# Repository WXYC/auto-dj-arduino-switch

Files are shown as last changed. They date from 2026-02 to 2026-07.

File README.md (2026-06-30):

# Auto DJ Arduino Switch

An Arduino Giga R1 WiFi sketch that **reports** the mixing board's AUX relay state and a manual toggle button to the [auto-dj-orchestrator](https://github.com/WXYC/auto-dj-orchestrator) over a WebSocket management channel (HTTP fallback over WiFi). The orchestrator owns all activation logic — it subscribes to AzuraCast and writes the flowsheet (to Backend-Service, which mirrors to tubafrenzy). This board is a "dumb" reporter: it reports inputs and drives a status LED.

> **Note:** Earlier firmware wrote tracks to tubafrenzy directly. That responsibility now lives in the orchestrator; the Arduino no longer polls AzuraCast or writes flowsheets. See [docs/networking-spec.md](docs/networking-spec.md).

## Why?

When auto DJ is playing and no DJ is logged into the flowsheet, those tracks are not recorded in WXYC's playback history. The orchestrator fills that gap; this device tells it when the auto DJ is on the air (relay) and lets an operator toggle it manually (button).

## Architecture

```mermaid
flowchart LR
    MB["Mixing Board<br>AUX Relay<br>(dry contact)"] -->|D2 pin| ARD["Arduino Giga R1 WiFi<br>Reports relay + button"]
    BTN["Toggle button"] -->|D5 pin| ARD
    ARD <-->|"WS mgmt channel<br>(HTTP fallback)"| ORCH["auto-dj-orchestrator"]
    ORCH <-->|Now Playing| AZ["AzuraCast<br>remote.wxyc.org"]
    ORCH -->|join / entry / end| BS["Backend-Service<br>(mirrors to tubafrenzy)"]
```

### Planned Architecture

A management server will sit between AzuraCast and the Arduino, subscribing to AzuraCast's Centrifugo real-time feed and relaying Now Playing updates over a single WebSocket that also carries management commands and heartbeat telemetry. An Ethernet shield provides the stable persistent connection required for WebSocket; WiFi remains as a fallback with direct AzuraCast polling.

```mermaid
flowchart LR
    MB["Mixing Board<br>AUX Relay"] -->|D2| ARD
    BTN["Toggle button"] -->|D5| ARD
    ARD["Arduino Giga R1 WiFi<br>(+ Ethernet Shield, Phase 2)"]
    ARD <-->|"WS mgmt channel<br>(heartbeat, button_toggle,<br>ack, commands)<br>HTTP fallback over WiFi"| ORCH["auto-dj-orchestrator"]
    ORCH <-->|now-playing| AZ["AzuraCast"]
    ORCH -->|flowsheet writes| BS["Backend-Service<br>(mirrors to tubafrenzy)"]
```

See [docs/networking-spec.md](docs/networking-spec.md) for the comprehensive networking specification (all protocols, authentication, shared types, and implementation phases). The [original roadmap](docs/remote-access-roadmap.md) is preserved for git history.

## State Machine

In the reporter model the state machine tracks connectivity only (it no longer runs a show lifecycle). It reports the relay level + button presses to the orchestrator and drives the status LED; `tick()` stays pure.

```mermaid
stateDiagram-v2
    [*] --> BOOTING
    BOOTING --> CONNECTING
    CONNECTING --> CONNECTED : link up + channel up
    CONNECTING --> ERROR_STATE : retries exhausted
    CONNECTED --> CONNECTING : channel dropped
    ERROR_STATE --> CONNECTING : link returns
```

- **BOOTING:** Pre-transport.
- **CONNECTING:** Bringing up a transport (Ethernet WS primary, WiFi fallback) and the management channel; covers the WiFi reconnect window.
- **CONNECTED:** A transport + the management channel are up. Reports relay changes and button presses, sends periodic heartbeats, handles commands (pause/resume/ping/restart), and drives the LED from the orchestrator-reported active flag.
- **ERROR_STATE:** Transport setup failed repeatedly; back off and retry.

## Hardware

- Arduino Giga R1 WiFi
- Arduino Ethernet Shield Rev2 (W5500 + SD)
- Dry contact relay from mixing board AUX channel
- 220 ohm resistor + LED (optional status indicator)

See [docs/wiring.md](docs/wiring.md) for wiring details.

## Enclosure

A modified 3D-printed enclosure based on the [GIGA Display Shield case](https://www.printables.com/model/605051), adapted for the Ethernet Shield Rev2. The enclosure is a sealed three-piece design (base, shield shelf, lid) with cutouts for RJ45, SD card, and a 4-position Euroblock screw terminal for the relay interface.

See [enclosure/README.md](enclosure/README.md) for build instructions, BOM, and assembly guide. The full mechanical specification is in [docs/enclosure-specification.md](docs/enclosure-specification.md).

## Required Libraries

Install via Arduino Library Manager:

| Library | Version | Purpose |
|---|---|---|
| ArduinoHttpClient | latest | HTTP GET/POST requests |
| ArduinoJson | v7+ | JSON parsing with filter documents |

The WiFi and WiFiSSLClient libraries are built into the Arduino Mbed OS GIGA board package.

## Setup

### 1. Install board support

In Arduino IDE, install **Arduino Mbed OS GIGA Boards** via Boards Manager.

### 2. Register the Arduino's MAC address

The Arduino connects to UNC-PSK WiFi. Register its MAC address at [UNC ITS](https://unc.edu/mydevices). To find the MAC address, upload a sketch that prints `WiFi.macAddress()` to Serial, or check the Serial output at boot (this sketch prints it during WiFi setup).

### 3. Configure secrets

```bash
cp auto-dj-arduino-switch/secrets.h.example auto-dj-arduino-switch/secrets.h
```

Edit `secrets.h` with:
- UNC-PSK WiFi password
- `AUTO_DJ_KEY` (must match the orchestrator's `AUTO_DJ_KEY` env var)

### 4. Orchestrator-side configuration

Set the `AUTO_DJ_KEY` environment variable on the [auto-dj-orchestrator](https://github.com/WXYC/auto-dj-orchestrator). The Arduino sends it as the `X-Auto-DJ-Key` header on the WebSocket upgrade (and the HTTP fallback), which the orchestrator validates with a timing-safe compare.

### 5. Upload

Open `auto-dj-arduino-switch/auto-dj-arduino-switch.ino` in Arduino IDE, select the Giga R1 WiFi board, and upload.

### 6. Wire the relay

Connect the mixing board's AUX relay contact to pin D2 and GND. See [docs/wiring.md](docs/wiring.md).

## Configuration

Edit `config.h` to change:

- Pin assignments (`RELAY_PIN`, `STATUS_LED_PIN`, `BUTTON_PIN`)
- Heartbeat / poll intervals
- Orchestrator host, port, paths, and `ORCHESTRATOR_USE_TLS`
- NTP server and timezone offset

## Serial Monitor

The sketch logs state transitions, track detections, and API calls to Serial at 115200 baud. Connect via Arduino IDE Serial Monitor for debugging.

## Maintenance

### Annual UNC-PSK password change

The UNC-PSK password changes yearly. Update `secrets.h` and re-upload the sketch. The Arduino's MAC address may also need re-registration.

### API key rotation

To rotate the key, update both:
1. `AUTO_DJ_KEY` in `secrets.h` on the Arduino
2. `AUTO_DJ_KEY` env var on the orchestrator

## Running Tests

Sketch modules are tested on desktop using GoogleTest with an Arduino shim layer. No Arduino hardware or SDK required. The shim provides `String`, `Print`, `Stream`, `Client`, GPIO stubs, and controllable `millis()`. Real ArduinoHttpClient and ArduinoJson libraries are compiled against the shim via CMake FetchContent.

**49 tests** cover:

| Module | Technique |
|---|---|
| `state_machine.h` | Pure `tick()`: connectivity transitions, retries/backoff, command handling, LED policy, heartbeat timing |
| `button_monitor.h` | Parameterized `update(millis, reading)` debounce (press-edge), bypasses GPIO |
| `relay_monitor.h` | Parameterized `update(millis, reading)` debounce, bypasses GPIO |
| `mgmt_protocol.h` | Pure ArduinoJson assembly (heartbeat/button_toggle/ack) + parsing (command, ack-result) |

`mgmt_client.cpp` (the WebSocket / HTTP-fallback I/O) is excluded from the desktop build — it `#include <ArduinoWebsockets.h>`, which is not available in CI — so all assembly/parsing lives in the pure `mgmt_protocol` module above.

```bash
cmake -B test/build test/
cmake --build test/build
cd test/build && ctest --output-on-failure
```

Tests run automatically on push and PR via GitHub Actions (`.github/workflows/test.yml`).

## Documentation

| Document | Scope |
|---|---|
| [docs/networking-spec.md](docs/networking-spec.md) | All network traffic, both flowsheet backends, credentials, management protocol, `wxyc-shared` types, implementation phases |
| [docs/remote-administration.md](docs/remote-administration.md) | Parameter inventory: every configurable value and why it might change |
| [docs/remote-access-roadmap.md](docs/remote-access-roadmap.md) | Original phased plan (superseded by networking-spec.md) |
| [docs/wiring.md](docs/wiring.md) | Hardware wiring: relay, LED, pin assignments |

## Known Limitations

- **WiFi reconnection blocks for ~36 seconds** (known Giga R1 firmware limitation). During this time, the state machine is frozen. Track changes during a WiFi outage are not logged retroactively.
- **No watchdog timer** yet. Long-running reliability depends on the Giga R1's stability. A hardware watchdog could be added for 24/7 operation.
- **NTP dependency:** If NTP time sync fails, the show cannot start (the `startingHour` and `workingHour` parameters require epoch milliseconds).

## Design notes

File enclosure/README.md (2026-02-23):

# Enclosure: Arduino GIGA R1 WiFi + Ethernet Shield Rev2

Modified 3D-printed enclosure for the auto DJ Arduino switch. Based on the [GIGA Display Shield case](https://www.printables.com/model/605051) (Printables model 605051), adapted to house an Ethernet Shield Rev2 instead of the Display Shield.

## Design Overview

Three-piece stacking enclosure:

1. **Base** -- main case body with GIGA R1 standoffs. Modified with RJ45, SD card, and terminal cutouts plus an internal support post.
2. **Shield shelf** -- internal platform that stacks inside the base. Modified with matching port cutouts.
3. **Lid** -- top cover. Display window filled solid for dust resistance.

Additionally:

4. **Terminal bracket** -- new part designed from scratch. Internal mount for the Euroblock screw terminal receptacle with strain relief.

## Modifications from Original

| Piece | Modification |
|---|---|
| Lid | Display window filled with solid block |
| Base | RJ45 cutout (left wall), SD cutout (right wall), terminal cutout (left wall), support post |
| Shelf | Matching RJ45, SD, and terminal cutouts aligned with base |
| Bracket | New part: terminal receptacle mount with M3 holes, dust lip, zip-tie slot |

## Port Layout

Looking at the enclosure from the left wall (-X):

```
+-------------------------------------------+
|                                            |
|   +--------+   >=6mm   +-----------+      |
|   |  RJ45  |           | Terminal  |      |
|   | 17x14.5|           | 18.4x10.4|      |
|   +--------+           +-----------+      |
|                                            |
+-------------------------------------------+
```

The SD card slot (13.0 x 3.5 mm) is on the opposite wall (+X), with a fingernail chamfer below.

## Building

Requires [OpenSCAD](https://openscad.org/) (`brew install --cask openscad`) and Python 3.10+.

```bash
# Render all output STLs
make stls

# Generate cross-section SVGs for paper templates
make cross-sections

# Render test slices for quick fit checks
make slices

# Build everything (STLs + slices + cross-sections)
make all

# Verify cutout dimensions against EAGLE BRD data
make verify

# Analyze original STL geometry
make analyze

# Remove all generated files
make clean
```

## File Structure

| File | Purpose |
|---|---|
| `config.scad` | All parameterized dimensions (edit this to tune fitment) |
| `lid.scad` | Modified lid: display window filled |
| `base.scad` | Modified base: port cutouts + support post |
| `shelf.scad` | Modified shelf: aligned port cutouts |
| `terminal_bracket.scad` | New part: internal connector mount |
| `board_model.scad` | Simplified Ethernet Shield 3D model for verification |
| `test_slices.scad` | Thin wall slices for pre-print fit testing |
| `cross_section.py` | Slices rendered STLs to generate 1:1 cross-section SVGs |
| `analyze_stl.py` | Extracts bounding boxes from original STLs |
| `verify_alignment.py` | Validates cutout positions against EAGLE BRD data |
| `Makefile` | Build targets for all outputs |
| `original/` | Unmodified STL files from Printables |
| `output/` | Rendered modified STLs, test slices, and SVGs |

## Verification Workflow

### 1. Python validation

```bash
make verify
```

Checks that all cutout dimensions and positions match EAGLE BRD component data within tolerance.

### 2. Visual inspection (OpenSCAD GUI)

Open `board_model.scad` overlaid inside the case to check:
- Cutout alignment (port housings protrude cleanly through cutouts)
- Interference detection (`intersection(case, board)` renders empty)
- Clearance gap uniformity

### 3. Paper templates

```bash
make cross-sections
```

Print the SVGs at 1:1 scale, cut out, and hold against physical boards.

### 4. Test slice prints

```bash
make slices
```

Print `output/test_slice_rj45_wall.stl` (~5 min) and `output/test_slice_sd_wall.stl` (~3 min) for quick fit checks before committing to a full print.

## Adjusting Fitment

All dimensions are parameterized in `config.scad`. Key parameters to tune:

| Parameter | Default | Description |
|---|---|---|
| `rj45_cutout_w` / `rj45_cutout_h` | 17.0 / 14.5 | RJ45 opening size |
| `sd_cutout_w` / `sd_cutout_h` | 13.0 / 3.5 | SD card opening size |
| `terminal_cutout_w` / `terminal_cutout_h` | 18.4 / 10.4 | Terminal opening size |
| `rj45_terminal_spacing` | 6.0 | Edge-to-edge spacing between RJ45 and terminal |
| `support_post_diameter` | 10.0 | Support post pad diameter |
| `eth_board_origin_x` / `_y` | (calculated) | Board-to-case position offset |
| `stacking_header_height` | 8.5 | Distance between GIGA R1 and Ethernet Shield PCBs |

After changing parameters, re-run `make verify` and `make all`.

## Bill of Materials

| Item | Qty | Notes |
|---|-----|---|
| 4-pos Euroblock plug (3.5 mm pitch) | 1 | Field-wire side |
| 4-pos Euroblock receptacle (3.5 mm pitch) | 1 | Panel side, mounts in bracket |
| 1x4 Molex KK 254 crimp housing (2.54 mm) | 1 | Arduino header end of internal harness |
| Molex KK crimp terminals | 4 | For internal harness |
| 24-26 AWG stranded wire (4 colors) | ~120 mm | Black (GND), White (D2), Green (D3), Red (+5V) |
| M3 x 25 mm bolts | 4 | Case assembly (original hardware) |
| M3 nuts | 4 | Case assembly (original hardware) |
| M3 x 8 mm bolts | 2 | Terminal bracket mounting |
| M3 heat-set inserts | 2 | Terminal bracket |
| TPU pad or 0.5 mm closed-cell foam | 1 | Support post cushion, ~10 mm diameter |
| Bootlace ferrules (optional) | 4 | Euroblock wire termination |

## Assembly Order

1. Install standoffs in base
2. Mount GIGA R1 board
3. Stack Ethernet Shield onto GIGA R1
4. Install terminal receptacle in bracket
5. Secure bracket to enclosure wall (M3 bolts into heat-set inserts)
6. Connect internal harness (Molex KK) to GIGA R1 header pins
7. Apply strain relief (zip tie through bracket slot)
8. Place TPU/foam pad on support post
9. Seat shield shelf
10. Install lid and secure with M3 bolts

## Reference

- [Enclosure specification](../docs/enclosure-specification.md) -- full mechanical and electrical spec
- [Wiring diagram](../docs/wiring.md) -- station-side relay wiring
- [Original case on Printables](https://www.printables.com/model/605051) -- GIGA Display Shield case (starting point)

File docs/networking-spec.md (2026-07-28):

# Networking Specification

This document specifies all network communication for the Auto DJ Arduino Switch -- every outbound HTTP call, every WebSocket message, every credential, and every server-side endpoint the device depends on or that depends on it.

## 1. Overview

> **Re-architecture note (reporter model).** The Arduino is now a **relay/button reporter**: it reports the AUX-relay state and a manual toggle button to the [auto-dj-orchestrator](https://github.com/WXYC/auto-dj-orchestrator) over the management channel and no longer polls AzuraCast or writes flowsheets. The orchestrator owns the AzuraCast subscription and all flowsheet writes, which go to **Backend-Service only** (Backend-Service — not this firmware — owns any legacy tubafrenzy mirror, for as long as that system runs). **The firmware has no tubafrenzy write path and no AzuraCast poll:** the `flowsheet_client.cpp` and `azuracast_client.cpp` modules that implemented them were **deleted** in the reporter re-architecture (commit `9facefc`). Sections below that describe the Arduino polling AzuraCast or writing to tubafrenzy directly (notably §1.2, §2.1, §2.3, §2.5, §3.2–§3.4, §4.1–§4.2, §6) — including any "Status: Implemented" markers and references to those deleted files — are **historical**: they document code that no longer exists in `main`. The authoritative parts for the current firmware are the management channel (§3.6–§3.8), activation sources (§2.7), and the type contracts (§5). Keeping the firmware free of a tubafrenzy write path is required by the [tubafrenzy decommissioning](https://github.com/WXYC/wiki/blob/main/plans/tubafrenzy-decommissioning.md) Phase 1 freeze ([WXYC/wiki#90](https://github.com/WXYC/wiki/issues/90)).

### 1.1 Purpose

The Auto DJ Arduino Switch is a networked embedded device that reports studio state (the AUX relay + a manual button) to the auto-dj-orchestrator, which bridges WXYC's auto DJ system ([AzuraCast](https://www.azuracast.com/)) with the station's flowsheet. This document is the source of truth for the auto-DJ network traffic.

### 1.2 Problem Statement

The device will sit inside the WXYC studio, wired into the mixing board. Once deployed, every configuration change -- including the annual UNC-PSK password rotation -- would require someone to walk to the studio with a laptop, connect via USB, and reflash the firmware. There would be no way to check whether the device is alive, inspect its state, or intervene remotely. For a device designed to run unattended, this is untenable.

Beyond remote access, WXYC is migrating its flowsheet infrastructure from the legacy [tubafrenzy](https://github.com/WXYC/tubafrenzy) system to [Backend-Service](https://github.com/WXYC/Backend-Service). Under the reporter model the firmware no longer writes flowsheets at all: it reports studio state to the [auto-dj-orchestrator](https://github.com/WXYC/auto-dj-orchestrator), which performs every flowsheet write against Backend-Service, authenticating as a service identity using JWT. Earlier firmware wrote to tubafrenzy directly; that path has been removed.

### 1.3 Document Scope

This document covers:

- All network traffic to and from the Arduino (HTTP, WebSocket, UDP)
- Flowsheet writes to Backend-Service, performed by the [auto-dj-orchestrator](https://github.com/WXYC/auto-dj-orchestrator) (the firmware itself no longer writes flowsheets)
- Shared type contracts via [`wxyc-shared`](https://github.com/WXYC/wxyc-shared) (`api.yaml`)
- Authentication and credential management for all connections
- The management server protocol (WebSocket + HTTP fallback)
- AzuraCast real-time now-playing via direct WebSocket (Centrifugo)
- Implementation phases

Related documents:

| Document | Scope |
|---|---|
| [remote-administration.md](remote-administration.md) | Parameter inventory: every configurable value, its current default, and why it might change |
| [wiring.md](wiring.md) | Hardware wiring: relay, LED, pin assignments |

### 1.4 Terminology

| Term | Definition |
|---|---|
| **tubafrenzy** | The legacy Java/Tomcat flowsheet system at `www.wxyc.info`. Form-encoded API, 302 redirect responses, `radioShowID` extracted from the Location header. |
| **Backend-Service** | The new Express/Node.js API at `api.wxyc.org`. JSON API, 200 JSON responses, `Show.id` from the response body. Uses [Better Auth](https://www.better-auth.com/) for authentication. |
| **AzuraCast** | The auto DJ and streaming software at `remote.wxyc.org`. Provides a now-playing API. |
| **Centrifugo** | The real-time messaging server embedded in AzuraCast. Publishes now-playing updates over WebSocket. |
| **management server** | The server that hosts the WebSocket management channel, heartbeat endpoints, and admin API. Could be Backend-Service or a standalone service. |
| **flowsheet** | The station's playback log -- a record of every song played during a show. |
| **`sh_id`** | AzuraCast's song history ID. A monotonically increasing integer unique per play event. Used to detect track changes. |
| **`radioShowID`** | tubafrenzy's show identifier. An integer extracted from the Location header after starting a show. |
| **`Show.id`** | Backend-Service's show identifier. An integer returned in the JSON response body after joining a show. |

---

## 2. System Architecture

### 2.1 Network Topology

All traffic flows are outbound from the Arduino. UNC campus networks are behind NAT with no inbound port access.

```mermaid
flowchart TD
    subgraph Studio["WXYC Studio"]
        ARD["Arduino Giga R1 WiFi<br>+ Ethernet Shield 2"]
    end

    subgraph External["External Services"]
        AZ["AzuraCast<br>remote.wxyc.org<br>(Now Playing API +<br>Centrifugo WebSocket)"]
        MS["Management Server<br>(auto-dj-orchestrator)<br>(WebSocket + REST)"]
        NTP["NTP Server<br>pool.ntp.org"]
    end

    subgraph Admin["Administration"]
        UI["Admin UI<br>(web dashboard)"]
    end

    ARD -- "HTTPS GET<br>now-playing poll<br>(WiFi fallback)" --> AZ
    ARD -. "WSS<br>now-playing push<br>(Ethernet, direct)" .-> AZ
    ARD -. "WSS / HTTPS<br>heartbeat + commands" .-> MS
    ARD -- "UDP :123<br>time sync" --> NTP

    UI -. "HTTPS<br>status + commands" .-> MS

    style MS stroke-dasharray: 5 5
```

Dashed lines indicate planned connections not yet implemented. Solid lines represent implemented functionality. **Historical note:** this topology predates the reporter re-architecture (§1). The firmware no longer POSTs to tubafrenzy (that edge and the tubafrenzy node have been removed) and, in the reporter model, no longer polls AzuraCast directly either — the orchestrator owns the AzuraCast subscription and all flowsheet writes. The firmware's current server relationships are the orchestrator management channel and NTP.

**Ethernet mode** (primary): All traffic flows through the W5500 Ethernet Shield with software TLS ([SSLClient](https://github.com/OPEnSLab-OSU/SSLClient) + [BearSSL](https://bearssl.org/)). The WebSocket to the management server stays open persistently.

**WiFi mode** (fallback): All traffic uses per-call `WiFiSSLClient` instances (destroyed after each request to avoid the Giga R1 global WiFiClient crash bug). No persistent connections. The management channel degrades to HTTP short polling.

### 2.2 Transport Strategy: Ethernet Primary, WiFi Fallback

Ethernet eliminates the WiFi stack's instability problems and enables persistent connections (WebSocket) that are impractical over WiFi. WiFi remains as a fallback if the Ethernet cable is unplugged or the jack goes dead.

```mermaid
flowchart TD
    Boot["Boot"] --> ETH{"Ethernet<br>link up?"}
    ETH -- Yes --> WSS["Open WebSocket (TLS)<br>over Ethernet"]
    ETH -- No --> WIFI["Connect to WiFi<br>(UNC-PSK)"]
    WIFI --> POLL["Short-poll fallback<br>(per-call HTTPS)"]

    WSS --> Run["Normal operation<br>(AzuraCast polling,<br>flowsheet writes,<br>management channel)"]
    POLL --> Run

    Run --> LinkLoss{"Connection<br>lost?"}
    LinkLoss -- "Ethernet cable<br>unplugged" --> WIFI
    LinkLoss -- "WiFi dropped" --> ETH
    LinkLoss -- "Both down" --> Wait["Retry loop<br>(Ethernet first,<br>then WiFi)"]
    Wait --> ETH
```

This means:

- **Ethernet + WebSocket** is the primary path. Persistent bidirectional connection. Commands arrive instantly. Heartbeats flow continuously.
- **WiFi + short polling** is the fallback. Uses the proven per-call `WiFiSSLClient` pattern that avoids the crash bug. Higher latency (up to 60 seconds) but reliable within the constraints of the WiFi stack.
- **WiFi password rotation** drops from "device is bricked" to "fallback path is degraded." The primary transport (Ethernet) doesn't use credentials that rotate.

#### Constraints

| Constraint | Detail |
|---|---|
| **Network** | UNC campus networks are behind NAT with no inbound port access. The Arduino cannot host a server reachable from outside campus. All remote access must be outbound-initiated. |
| **Hardware** | [Arduino Giga R1 WiFi](https://docs.arduino.cc/hardware/giga-r1-wifi/) ([STM32H747XI](https://www.st.com/en/microcontrollers-microprocessors/stm32h747xi.html)). 1 MB SRAM, 2 MB internal flash, 16 MB QSPI flash. The firmware does not currently use persistent storage. |
| **Ethernet** | An [Arduino Ethernet Shield 2](https://docs.arduino.cc/hardware/ethernet-shield-rev2/) (W5500, SPI-based) can be mounted on the Giga R1's Mega-compatible headers. The W5500 has a hardware TCP/IP stack. The studio needs a live Ethernet jack (verify with UNC ITS). |
| **WiFi** | Built-in WiFi (UNC-PSK, WPA2). `WiFi.begin()` blocks for up to 36 seconds on reconnection (known Giga R1 firmware bug). A global `WiFiSSLClient` crashes the board; the current code creates and destroys one per HTTP call as a workaround. |
| **TLS** | The W5500 handles TCP but not TLS. Software TLS is required for HTTPS over Ethernet (via `SSLClient` + BearSSL or [Mbed TLS](https://github.com/Mbed-TLS/mbedtls)). The STM32H747's Cortex-M7 at 480 MHz has ample power for this. `WiFiSSLClient` handles TLS in the WiFi module's firmware and is unaffected. |
| **Existing infra** | The firmware already implements outbound HTTPS calls to `remote.wxyc.org` (AzuraCast) and `www.wxyc.info` (tubafrenzy). |

**NTP**: When Ethernet is the active transport, `WiFi.getTime()` is unavailable. The [`NTPClient`](https://github.com/arduino-libraries/NTPClient) library (Fabrice Weinberg) provides NTP over `EthernetUDP`. The `NetworkManager` exposes a `getTime()` method that delegates to `WiFi.getTime()` or `NTPClient::getEpochTime()` depending on the active transport. See [Section 3.5](#35-outbound-udp-ntp-time-sync).

### 2.3 Flowsheet Write Architecture

Under the reporter model the Arduino writes no flowsheet entries. Every flowsheet write is performed by the [auto-dj-orchestrator](https://github.com/WXYC/auto-dj-orchestrator) against Backend-Service, authenticating as a service identity using standard JWT refresh (see [unified-auth-system.md](https://github.com/WXYC/docs/blob/main/unified-auth-system.md)). The table below is retained for reference: the left column is the **legacy Arduino → tubafrenzy path, now removed**; the right column is the current orchestrator path.

| | Legacy Arduino → tubafrenzy (removed) | Orchestrator → Backend-Service |
|--|---|---|
| **Content type** | `application/x-www-form-urlencoded` | `application/json` |
| **Auth** | `X-Auto-DJ-Key` header | `Authorization: Bearer <JWT>` (service account) |
| **Start show** | POST `/playlists/startRadioShow` → 302, `radioShowID` from Location header | POST `/flowsheet/join` → 200 JSON, `Show.id` from response body |
| **Add entry** | POST `/playlists/flowsheetEntryAdd` → 302 | POST `/flowsheet` → 200 JSON |
| **End show** | POST `/playlists/finishRadioShow` → 302 | POST `/flowsheet/end` → 200 JSON |
| **Breakpoints** | Server auto-inserts via `autoBreakpoint=true` | Client must POST explicit breakpoint entry |
| **DJ ID** | `"0"` (string, no DJ table) | Resolved server-side from service identity |

**Why the Arduino doesn't talk to Backend-Service directly**: Backend-Service uses JWT authentication with token refresh. The Arduino's constrained environment (no `jose`, limited RAM, BearSSL-only TLS) makes JWT refresh impractical. The orchestrator is a server-side Node.js service that handles JWT lifecycle naturally. This eliminates the PAT vs JWT conflict — the Arduino uses a simple shared secret (`X-Auto-DJ-Key`) for the orchestrator management channel only, while the orchestrator handles all JWT-authenticated communication.

**Data flow**: The orchestrator writes to Backend-Service (JWT) exclusively; any mirror to the legacy tubafrenzy system is owned by Backend-Service, not the orchestrator, and not this firmware. There is **no Arduino tubafrenzy fallback path** — that path was removed in the reporter re-architecture, and the orchestrator has no dual-backend `FLOWSHEET_BACKEND` selector (it was built Backend-only; see [auto-dj-orchestrator#1](https://github.com/WXYC/auto-dj-orchestrator/issues/1)).

### 2.4 Management Server

The management server is the remote administration layer for the Arduino. It provides device visibility (is the Arduino alive? what's it doing?), remote control (pause, resume, force-end show), and credential rotation -- without physical access to the studio.

**Responsibilities**:

| Responsibility | Description | Protocol reference |
|---|---|---|
| **Heartbeat tracking** | Receive periodic heartbeats from the Arduino (every 30s over WebSocket, every 60s over HTTP). Maintain a `AutoDJDeviceStatus` record with last-seen timestamp, uptime, transport, error counts. Mark the device offline if no heartbeat arrives within 60s. | [Section 3.6.2](#362-message-types), [3.7](#37-http-fallback-management-polling-wifi) |
| **Command dispatch** | Accept commands from the admin UI (`pause`, `resume`, `end_show`, `set_config`, `restart`, `ping`), enqueue them, and deliver them to the Arduino over WebSocket or HTTP poll. Track pending commands until acknowledged. | [Section 3.6.3](#363-supported-commands), [3.8](#38-server-side-endpoints) |
| **Acknowledgment processing** | Receive acks from the Arduino confirming command execution. Dequeue the command, update status. Surface errors to the admin UI. | [Section 3.6.2](#362-message-types) |
| **Error report relay** | Receive structured error reports from the Arduino and forward them to [Sentry](https://sentry.io/) or another error tracking service. Alert on `fatal`-level errors. | [Section 3.6.2](#362-message-types) |
| **Credential rotation** | Push new API keys to the Arduino via `set_config` commands. Coordinate the two-phase rotation protocol (accept both old and new, then revoke old). | [Section 4.6](#46-credential-rotation-protocol) |
| **Admin API** | Expose device status and command endpoints to the admin UI, authenticated via Better Auth (session cookies or JWT, `stationManager` role). | [Section 3.8](#38-server-side-endpoints), [4.5](#45-management-server-auth-admin-facing) |

**What the management server does NOT do**: The now-playing feed does **not** flow through the management server. The Arduino subscribes directly to AzuraCast's Centrifugo WebSocket ([Section 3.9](#39-azuracast-centrifugo-direct-websocket)). The management server handles only device management -- it never touches flowsheet data or track metadata. (The relay architecture was considered and rejected; see [Appendix B](#appendix-b-azuracast-centrifugo-integration-details).)

**Dual-transport interface**: The management server exposes the same logical operations over two transports to match the Arduino's network mode:

| Transport | Arduino mode | Channel | Latency |
|---|---|---|---|
| **WebSocket** (`/api/auto-dj/ws`) | Ethernet (primary) | Persistent bidirectional connection | Real-time |
| **HTTP** (`/api/auto-dj/heartbeat`, `/api/auto-dj/commands`) | WiFi (fallback) | Short polling every 60s | Up to 60s |

The Arduino determines which transport to use based on `NetworkManager` state ([Section 2.2](#22-transport-strategy-ethernet-primary-wifi-fallback)). The management server accepts both simultaneously -- it does not need to know the Arduino's current transport mode.

**Auth model**: Two audiences, two auth mechanisms (Sections [4.4](#44-management-server-auth-arduino-facing), [4.5](#45-management-server-auth-admin-facing)):

- **Arduino-facing**: `X-Auto-DJ-Key` header (shared secret, timing-safe comparison)
- **Admin-facing**: Better Auth session/JWT (`stationManager` role required)

**Server choice**: Backend-Service (Express/Node.js) is a natural fit -- it already has WebSocket infrastructure via the `ws` package, uses Better Auth for admin authentication, and is the actively maintained backend. A standalone lightweight service (Hono or Fastify on Railway) is an alternative that keeps the management concern decoupled. See [Appendix A](#appendix-a-server-choice-analysis) for the full comparison.

### 2.5 AzuraCast (Now-Playing Source)

AzuraCast is the auto DJ and streaming software at `remote.wxyc.org`. From the Arduino's perspective, its sole role is to answer the question: *what song is playing right now?* The Arduino uses this to detect track changes and post entries to the flowsheet.

AzuraCast exposes now-playing data through two interfaces. The Arduino uses both, switching based on network mode:

| Interface | Protocol | Endpoint | Latency | Transport | Status |
|---|---|---|---|---|---|
| **Static HTTP** | HTTPS GET | `/api/nowplaying_static/main.json` | Up to 20s (poll interval) | Both (WiFi + Ethernet) | **Implemented** |
| **Centrifugo WebSocket** | WSS | `/api/live/nowplaying/websocket` | Near-real-time (push) | Ethernet only | Planned |

Both interfaces are **public** -- no authentication required. Both return the same logical data (`sh_id`, `artist`, `title`, `album`, `is_live`). The [ArduinoJson](https://arduinojson.org/) filter document is identical for both. The `AzuraCastClient` consumes the same fields regardless of source.

**Dual-mode strategy** ([Section 3.9.2](#392-dual-mode-architecture)):

- **Ethernet (push mode)**: Subscribe to Centrifugo WebSocket for near-real-time track change notifications. A 60-second safety-net HTTP poll catches any missed messages.
- **WiFi (poll mode)**: Poll the static HTTP endpoint every 20 seconds. No persistent connections. This is the current implemented behavior.

**What AzuraCast is NOT**: AzuraCast is an external system operated by WXYC's streaming infrastructure team, not something this project builds or deploys. The Arduino treats it as a read-only data source. AzuraCast has no knowledge of the Arduino, the flowsheet, or the management server. The now-playing feed is completely independent of the management channel ([Section 2.4](#24-management-server)).

See [Section 3.2](#32-outbound-http-azuracast-now-playing) for the HTTP polling protocol and [Section 3.9](#39-azuracast-centrifugo-direct-websocket) for the Centrifugo WebSocket protocol.

### 2.6 Admin UI

The admin UI is a web dashboard that gives station managers remote visibility into the Arduino's state and the ability to issue commands to it. It communicates exclusively with the management server ([Section 2.4](#24-management-server)) -- it never talks to the Arduino directly.

**Capabilities**:

| Capability | Management server endpoint | Description |
|---|---|---|
| **Device status** | `GET /api/auto-dj/status` | View current state: online/offline, active transport (Ethernet/WiFi), uptime, last heartbeat timestamp, current show state, error counts, last track posted |
| **Issue commands** | `POST /api/auto-dj/commands` | Send commands: `pause`, `resume`, `end_show`, `restart`, `ping`, `set_config` |
| **Command history** | (derived from status) | View pending commands and their ack status |
| **Error visibility** | (derived from status) | View recent error reports relayed from the Arduino |

**Auth**: Better Auth session cookies or JWT. Only users with the `stationManager` role (or a to-be-defined `admin` capability) can access these endpoints ([Section 4.5](#45-management-server-auth-admin-facing)).

**Scope**: [Open Question 4](#8-open-questions) asks whether the admin UI should be a full dashboard or a minimal status page. The initial implementation should be minimal -- the management server's REST API is the primary contract, and a simple UI can be layered on top.

**Deployment**: Not yet decided. Options include:

- A page within [dj-site](https://github.com/WXYC/dj-site) (already uses Better Auth, already deployed to Cloudflare Pages)
- A standalone single-page app
- A server-rendered page served by Backend-Service itself

**Types consumed**: The admin UI imports `AutoDJDeviceStatus` and `AutoDJHeartbeat` from `wxyc-shared` ([Section 5.5](#55-consumer-matrix)). These types are generated from `api.yaml`, so the UI gets compile-time type safety against the management server's responses.

**Phase**: The admin UI is part of Phase 3 ([Section 7.4](#74-phase-3-websocket-management--azuracast-direct-websocket)), tracked as a 14-day task (`p3d`) that runs in parallel with the WebSocket management client work.

### 2.7 Activation Sources

The auto-DJ system can be activated and deactivated from three sources. All activation logic lives in the orchestrator ([auto-dj-orchestrator](https://github.com/WXYC/auto-dj-orchestrator)) -- the Arduino reports inputs but does not make activation decisions.

| Source | Trigger | How it reaches the orchestrator | Section |
|---|---|---|---|
| **Virtual switch** | DJ clicks activate/deactivate in [dj-site](https://github.com/WXYC/dj-site) | `POST /api/auto-dj/activate` or `/deactivate` on the orchestrator | [3.10](#310-virtual-switch-api) |
| **Physical button** | Mushroom head button press on Arduino | Arduino sends a `button_toggle` message over the management channel (WebSocket or HTTP fallback) | [3.6.2](#362-message-types), [3.7](#37-http-fallback-management-polling-wifi) |
| **Relay** | Mixing board AUX relay state change | Arduino reports relay state in heartbeat; orchestrator auto-deactivates when relay indicates a live DJ is broadcasting | [3.6.2](#362-message-types) |

#### Conflict Resolution

1. **Live DJ always wins.** If the relay reports a live DJ (`is_live: true` from AzuraCast, or relay open), the orchestrator deactivates auto-DJ regardless of the virtual switch or button state. The status response shows `deactivatedBy.source: "relay"`.

2. **Button and virtual switch are equivalent.** Both toggle the orchestrator's activation state. The last action wins. There is no precedence between them.

3. **No automatic reactivation after live DJ.** When the relay transitions back to auto-DJ-active (live DJ signs off), the orchestrator does NOT automatically reactivate. A DJ must explicitly activate via the virtual switch or the physical button. This prevents the auto-DJ from unexpectedly resuming after a DJ finishes their show.

#### Physical Button Hardware

The Arduino has a 22mm industrial mushroom head button (momentary, spring return) on D5 (`BUTTON_PIN`), debounced identically to the relay input (50ms). See [wiring.md](wiring.md) for the full wiring guide. The button uses the NO (normally open) contact: at rest D5 reads HIGH (internal pullup), and pressing the button pulls D5 LOW.

The button does NOT directly affect the Arduino's state machine. On a debounced press, the Arduino sends a `button_toggle` message to the orchestrator via the management channel ([Section 3.6.2](#362-message-types)). Over WiFi fallback, the press is reported in the next heartbeat via the `button_press_count` field ([Section 3.7](#37-http-fallback-management-polling-wifi)). The orchestrator decides whether to activate or deactivate based on its current state, and the result flows back to the Arduino via the standard ack/command mechanism.

Before the orchestrator is deployed, the button is wired and debounced but has no effect. The Arduino continues to operate in relay-only mode.

---

## 3. Protocol Reference

### 3.1 Traffic Summary Table

| # | Direction | Protocol | Endpoint / Channel | Auth | Content Type | Transport | Status |
|---|---|---|---|---|---|---|---|
| 1 | ~~Arduino → AzuraCast~~ | HTTPS GET | `/api/nowplaying_static/main.json` | None (public) | JSON response | Both | **Removed** (reporter re-arch) |
| 2 | ~~Arduino → tubafrenzy~~ | HTTPS POST | `/playlists/startRadioShow` | `X-Auto-DJ-Key` | Form-encoded | Both | **Removed** (reporter re-arch) |
| 3 | ~~Arduino → tubafrenzy~~ | HTTPS POST | `/playlists/flowsheetEntryAdd` | `X-Auto-DJ-Key` | Form-encoded | Both | **Removed** (reporter re-arch) |
| 4 | ~~Arduino → tubafrenzy~~ | HTTPS POST | `/playlists/finishRadioShow` | `X-Auto-DJ-Key` | Form-encoded | Both | **Removed** (reporter re-arch) |
| 5 | Orchestrator → Backend-Service | HTTPS POST | `/flowsheet/join` | Bearer JWT | JSON | N/A (server-side) | Planned |
| 6 | Orchestrator → Backend-Service | HTTPS POST | `/flowsheet` | Bearer JWT | JSON | N/A (server-side) | Planned |
| 7 | Orchestrator → Backend-Service | HTTPS POST | `/flowsheet/end` | Bearer JWT | JSON | N/A (server-side) | Planned |
| 8 | Arduino ↔︎ AzuraCast | WSS | `/api/live/nowplaying/websocket` | None (public) | JSON frames | Ethernet | Planned |
| 9 | Arduino → NTP | UDP | `pool.ntp.org:123` | None | NTP packet | Ethernet | Planned |
| 10 | Arduino ↔︎ Mgmt Server | WSS | `/api/auto-dj/ws` | `X-Auto-DJ-Key` | JSON frames | Ethernet | Planned |
| 11 | Arduino → Mgmt Server | HTTPS POST | `/api/auto-dj/heartbeat` | `X-Auto-DJ-Key` | JSON | WiFi (fallback) | Planned |
| 12 | Arduino → Mgmt Server | HTTPS GET | `/api/auto-dj/commands` | `X-Auto-DJ-Key` | JSON response | WiFi (fallback) | Planned |
| 13 | Admin UI → Mgmt Server | HTTPS POST | `/api/auto-dj/commands` | Better Auth session | JSON | N/A | Planned |
| 14 | Admin UI → Mgmt Server | HTTPS GET | `/api/auto-dj/status` | Better Auth session | JSON response | N/A | Planned |
| 15 | Arduino → NTP | WiFi.getTime() | (internal to WiFi module) | None | NTP | WiFi | **Implemented** |
| 16 | dj-site → Orchestrator | HTTPS POST | `/api/auto-dj/activate` | Better Auth JWT | JSON | N/A | Planned |
| 17 | dj-site → Orchestrator | HTTPS POST | `/api/auto-dj/deactivate` | Better Auth JWT | JSON | N/A | Planned |
| 18 | dj-site → Orchestrator | HTTPS GET | `/api/auto-dj/status` | Better Auth JWT | JSON response | N/A | Planned |

Rows 1–4 are struck through and marked **Removed**: they described the firmware's direct AzuraCast poll and tubafrenzy writes, both deleted in the reporter re-architecture (§1). The now-playing subscription and all flowsheet writes are now the orchestrator's; §3.2–§3.4 below are retained as historical / orchestrator-contract reference.

### 3.2 Outbound HTTP: AzuraCast Now Playing

**Status**: Removed from the firmware in the reporter re-architecture (`azuracast_client.cpp` was deleted). The orchestrator now owns the AzuraCast now-playing subscription; the protocol below documents how the firmware used to poll and remains a useful reference for the orchestrator's equivalent poll.

Historically, the Arduino polled AzuraCast's static now-playing endpoint to detect track changes.

| Field | Value |
|---|---|
| **Method** | GET |
| **URL** | `https://remote.wxyc.org/api/nowplaying_static/main.json` |
| **Auth** | None (public endpoint) |
| **Response** | ~10 KB JSON, Nginx-cached |
| **Poll interval** | 20 seconds (`POLL_INTERVAL_MS`) |

**ArduinoJson filter document** (parses only needed fields, keeping memory under 1 KB):

```cpp
JsonDocument filter;
filter["now_playing"]["sh_id"] = true;
filter["now_playing"]["song"]["artist"] = true;
filter["now_playing"]["song"]["title"] = true;
filter["now_playing"]["song"]["album"] = true;
filter["live"]["is_live"] = true;
```

**Parsed fields**:

| JSON Path | Type | Purpose |
|---|---|---|
| `now_playing.sh_id` | `int` | Song history ID. Monotonically increasing. A new value means a new track. |
| `now_playing.song.artist` | `string` | Artist name for the flowsheet entry. |
| `now_playing.song.title` | `string` | Track title for the flowsheet entry. |
| `now_playing.song.album` | `string` | Album title for the flowsheet entry. |
| `live.is_live` | `bool` | `true` when a live DJ is broadcasting (the Arduino ignores this state -- the relay contact is the primary signal). |

**Track change detection**: Compare `sh_id` to the previous value. If different, a new track is playing. The first poll after boot always triggers (previous `sh_id` is 0).

### 3.3 Outbound HTTP: tubafrenzy Flowsheet Operations

**Status**: Removed from the firmware in the reporter re-architecture (`flowsheet_client.cpp` was deleted). The firmware performs no tubafrenzy writes; the orchestrator performs all flowsheet writes against Backend-Service. The tubafrenzy protocol below is retained as historical reference only.

Historically, all tubafrenzy requests were form-encoded POSTs authenticated by the `X-Auto-DJ-Key` header. The server responds with 302 redirects on success (the servlet redirects to a JSP page, but the Arduino does not follow the redirect). [`ArduinoHttpClient`](https://github.com/arduino-libraries/ArduinoHttpClient) does not follow redirects by default, which is the desired behavior.

#### 3.3.1 Start Show

| Field | Value |
|---|---|
| **Method** | POST |
| **URL** | `https://www.wxyc.info/playlists/startRadioShow` |
| **Content-Type** | `application/x-www-form-urlencoded` |
| **Auth** | `X-Auto-DJ-Key: <key>` |
| **Success response** | 302 with Location header containing the new `radioShowID` |

**Request body parameters**:

| Parameter | Value | Source |
|---|---|---|
| `djID` | `"0"` | `AUTO_DJ_ID` in `config.h` |
| `djName` | `"Auto DJ"` | `AUTO_DJ_NAME` in `config.h` (URL-encoded) |
| `djHandle` | `"AutoDJ"` | `AUTO_DJ_HANDLE` in `config.h` (URL-encoded) |
| `showName` | `"Auto DJ"` | `AUTO_DJ_SHOW_NAME` in `config.h` (URL-encoded) |
| `startingHour` | epoch milliseconds | `currentHourMs()` from [`utils.cpp`](../auto-dj-arduino-switch/utils.cpp) |

**Response handling**: Parse `radioShowID` from the Location header using `parseRadioShowID()` (in `utils.cpp`). Returns -1 on failure.

#### 3.3.2 Add Flowsheet Entry

| Field | Value |
|---|---|
| **Method** | POST |
| **URL** | `https://www.wxyc.info/playlists/flowsheetEntryAdd` |
| **Content-Type** | `application/x-www-form-urlencoded` |
| **Auth** | `X-Auto-DJ-Key: <key>` |
| **Success response** | 302 |

**Request body parameters**:

| Parameter | Value | Source |
|---|---|---|
| `radioShowID` | integer | From `startShow()` response |
| `workingHour` | epoch milliseconds | `currentHourMs()` from `utils.cpp` |
| `artistName` | string | From AzuraCast `now_playing.song.artist` (URL-encoded) |
| `songTitle` | string | From AzuraCast `now_playing.song.title` (URL-encoded) |
| `releaseTitle` | string | From AzuraCast `now_playing.song.album` (URL-encoded) |
| `releaseType` | `"otherRelease"` | Hardcoded |
| `autoBreakpoint` | `"true"` | Tells the server to auto-insert hourly breakpoints via `FlowsheetEntryService.createEntryWithAutoBreakpoints()` |

#### 3.3.3 End Show

| Field | Value |
|---|---|
| **Method** | POST |
| **URL** | `https://www.wxyc.info/playlists/finishRadioShow` |
| **Content-Type** | `application/x-www-form-urlencoded` |
| **Auth** | `X-Auto-DJ-Key: <key>` |
| **Success response** | 302 |

**Request body parameters**:

| Parameter | Value | Source |
|---|---|---|
| `radioShowID` | integer | From `startShow()` response |
| `mode` | `"signoffConfirm"` | Skips the interactive JSP confirmation page |

### 3.4 Backend-Service Flowsheet Operations (via Orchestrator)

**Status**: Planned (orchestrator responsibility)

The Arduino does not communicate with Backend-Service directly. All Backend-Service flowsheet operations are performed by the [auto-dj-orchestrator](https://github.com/WXYC/auto-dj-orchestrator), which authenticates as a service identity (`auto-dj-orchestrator@services.wxyc.org`) using JWT with standard token refresh. See [Section 2.3](#23-flowsheet-write-architecture) for the rationale.

The following endpoint specifications describe the orchestrator's Backend-Service communication. They are documented here for completeness since the orchestrator implements the same logical flowsheet operations as the Arduino's tubafrenzy client. All requests are JSON POSTs authenticated by a Bearer token (JWT). Responses are 200 with JSON bodies.

#### 3.4.1 Join Show

| Field | Value |
|---|---|
| **Method** | POST |
| **URL** | `https://api.wxyc.org/flowsheet/join` |
| **Content-Type** | `application/json` |
| **Auth** | `Authorization: Bearer <JWT>` |
| **Success response** | 200 JSON (`Show` or `ShowDJ`) |

**Request body**:

```json
{
    "show_name": "Auto DJ"
}
```

| Field | Type | Source |
|---|---|---|
| `show_name` | `string` | Orchestrator configuration |

Backend-Service resolves the Auto DJ's `dj_id` server-side from the orchestrator's service identity (`auto-dj-orchestrator`). The orchestrator does not supply a `dj_id` — this eliminates client trust for identity.

**Response** (`Show` schema):

```json
{
    "id": 789,
    "primary_dj_id": 42,
    "show_name": "Auto DJ",
    "start_time": "2026-02-20T03:00:00.000Z",
    "end_time": null
}
```

The `id` field is the show identifier used for subsequent operations (equivalent to tubafrenzy's `radioShowID`).

#### 3.4.2 Add Flowsheet Entry

| Field | Value |
|---|---|
| **Method** | POST |
| **URL** | `https://api.wxyc.org/flowsheet` |
| **Content-Type** | `application/json` |
| **Auth** | `Authorization: Bearer <JWT>` |
| **Success response** | 200 JSON (`FlowsheetEntryResponse`) |

**Request body** (freeform song entry):

```json
{
    "artist_name": "Yo La Tengo",
    "album_title": "I Can Hear the Heart Beating as One",
    "track_title": "Autumn Sweater",
    "request_flag": false,
    "record_label": ""
}
```

| Field | Type | Required | Source |
|---|---|---|---|
| `artist_name` | `string` | Yes | From AzuraCast `now_playing.song.artist` |
| `album_title` | `string` | Yes | From AzuraCast `now_playing.song.album` |
| `track_title` | `string` | Yes | From AzuraCast `now_playing.song.title` |
| `request_flag` | `boolean` | Yes | Always `false` for auto DJ |
| `record_label` | `string` | No | Empty string (not available from AzuraCast) |

Note: The `show_id` is implicit -- Backend-Service tracks the active show for each DJ via the `/flowsheet/join` state.

#### 3.4.3 End Show

| Field | Value |
|---|---|
| **Method** | POST |
| **URL** | `https://api.wxyc.org/flowsheet/end` |
| **Content-Type** | `application/json` |
| **Auth** | `Authorization: Bearer <JWT>` |
| **Success response** | 200 JSON (`Show` or `ShowDJ`) |

**Request body**: Empty. Backend-Service identifies the orchestrator's active show from the service identity.

#### 3.4.4 Add Breakpoint (Backend-Service only)

Unlike tubafrenzy (which auto-inserts breakpoints via `autoBreakpoint=true`), Backend-Service requires the client to explicitly POST a breakpoint entry at the top of each hour. See [Section 6.6](#66-show-lifecycle-differences) for the abstraction that normalizes this.

**Request body** (message entry with breakpoint content):

```json
{
    "message": "BREAKPOINT"
}
```

#### 3.4.5 Show Lifecycle Comparison

The full show lifecycle, showing the key protocol differences between the **historical** Arduino → tubafrenzy flow (top rect — removed in the reporter re-architecture) and the current orchestrator → Backend-Service flow:

```mermaid
sequenceDiagram
    participant Arduino
    participant TF as tubafrenzy
    participant ORCH as auto-dj-orchestrator
    participant BS as Backend-Service

    rect rgb(200, 220, 240)
    Note over Arduino,TF: Arduino → tubafrenzy (historical — removed)
    Arduino->>TF: POST /playlists/startRadioShow<br/>(form-encoded, X-Auto-DJ-Key)
    TF-->>Arduino: 302 Location: ...radioShowID=12345

    loop Each track change
        Arduino->>TF: POST /playlists/flowsheetEntryAdd<br/>(autoBreakpoint=true)
        TF-->>Arduino: 302
    end

    Arduino->>TF: POST /playlists/finishRadioShow
    TF-->>Arduino: 302
    end

    rect rgb(220, 240, 200)
    Note over ORCH,BS: Orchestrator → Backend-Service (planned)
    ORCH->>BS: POST /flowsheet/join<br/>(JSON, Bearer JWT)
    BS-->>ORCH: 200 {"id": 789, ...}

    loop Each track change
        ORCH->>BS: POST /flowsheet
        BS-->>ORCH: 200 JSON
    end

    opt Hour boundary
        ORCH->>BS: POST /flowsheet<br/>{"message": "BREAKPOINT"}
        BS-->>ORCH: 200 JSON
    end

    ORCH->>BS: POST /flowsheet/end
    BS-->>ORCH: 200 JSON
    end
```

### 3.5 Outbound UDP: NTP Time Sync

**Status**: Implemented over WiFi (`WiFi.getTime()`), planned over Ethernet (`NTPClient`)

| Field | Value |
|---|---|
| **Protocol** | UDP |
| **Server** | `pool.ntp.org` |
| **Port** | 123 |
| **Purpose** | UTC epoch time for flowsheet timestamps (`startingHour`, `workingHour`), heartbeat telemetry, and human-readable local time display (via `localEpoch()`) |

**WiFi transport**: `WiFi.getTime()` handles NTP internally within the WiFi module firmware. No explicit UDP required.

**Ethernet transport**: The `NTPClient` library (Fabrice Weinberg) sends NTP requests over `EthernetUDP`. API: `ntpClient.getEpochTime()`.

The `NetworkManager` exposes a unified `getTime()` method:

```cpp
unsigned long NetworkManager::getTime() {
    if (activeTransport == ETHERNET) {
        ntpClient.update();
        return ntpClient.getEpochTime();
    }
    return WiFi.getTime();  // WiFi module handles NTP internally
}
```

### 3.6 WebSocket: Management Channel

**Status**: Planned (Phase 3)

The WebSocket management channel provides real-time bidirectional communication between the Arduino and the management server. It carries heartbeats, commands, acknowledgments, now-playing relay data, and error reports.

#### 3.6.1 Connection Lifecycle

```mermaid
sequenceDiagram
    participant Arduino
    participant Server as Management Server
    participant Admin as Admin UI
    participant AZ as AzuraCast

    Note over Arduino: Boot complete,<br/>Ethernet link up

    Arduino->>Server: WebSocket upgrade<br/>(wss://server/api/auto-dj/ws)<br/>X-Auto-DJ-Key header
    Server-->>Arduino: 101 Switching Protocols

    Arduino->>AZ: WebSocket upgrade<br/>(wss://remote.wxyc.org/api/live/nowplaying/websocket)
    AZ-->>Arduino: 101 Switching Protocols
    Arduino->>AZ: {"subs": {"station:shortcode": {"recover": true}}}
    AZ-->>Arduino: Initial now_playing data (cached)

    loop Every 30s
        Arduino->>Server: {"type": "heartbeat", ...}
    end

    AZ->>Arduino: Now playing update (track change)

    Admin->>Server: POST /api/auto-dj/commands<br/>{"action": "pause"}
    Server->>Arduino: {"type": "command", "id": "x1", "action": "pause"}
    Arduino->>Server: {"type": "ack", "id": "x1", "status": "ok"}

    Note over Arduino: Ethernet cable unplugged
    Note over Arduino: Both WebSockets drop

    Arduino->>Arduino: Failover to WiFi

    loop Every 60s (short-poll fallback)
        Arduino->>Server: POST /api/auto-dj/heartbeat<br/>{..., "transport": "wifi"}
        Server-->>Arduino: 200 OK
        Arduino->>Server: GET /api/auto-dj/commands
        Server-->>Arduino: (pending commands or empty)
    end

    Note over Arduino: Ethernet cable restored
    Arduino->>Server: WebSocket upgrade (reconnect)
    Server-->>Arduino: 101 Switching Protocols
    Note over Arduino: Back to WebSocket
```

#### 3.6.2 Message Types

All WebSocket messages are JSON objects with a `type` discriminator field.

**Heartbeat** (Arduino → Server):

```json
{
    "type": "heartbeat",
    "state": "AUTO_DJ_ACTIVE",
    "transport": "ethernet",
    "uptime_s": 86402,
    "wifi_rssi": null,
    "free_ram": 524288,
    "radio_show_id": 12345,
    "last_track": {
        "artist": "Yo La Tengo",
        "title": "Autumn Sweater",
        "posted_at": 1708400000
    },
    "last_error": null,
    "firmware_version": "1.2.0",
    "config_hash": "a3f2c8",
    "loop_max_ms": 45,
    "reconnect_count": 0,
    "tracks_detected": 142,
    "tracks_posted": 140,
    "errors_since_boot": 2,
    "button_press_count": 0
}
```

| Field | Type | Description |
|---|---|---|
| `type` | `"heartbeat"` | Message discriminator |
| `state` | `string` | Current state machine state (`BOOTING`, `CONNECTING_WIFI`, `IDLE`, `STARTING_SHOW`, `AUTO_DJ_ACTIVE`, `ENDING_SHOW`, `ERROR_STATE`) |
| `transport` | `string` | Active transport (`"ethernet"` or `"wifi"`) |
| `uptime_s` | `integer` | Seconds since boot |
| `wifi_rssi` | `integer \| null` | WiFi signal strength in dBm, or `null` if on Ethernet |
| `free_ram` | `integer` | Free heap bytes |
| `radio_show_id` | `integer \| null` | Active show ID, or `null` if no show is in progress |
| `last_track` | `object \| null` | Last track posted to the flowsheet |
| `last_track.artist` | `string` | Artist name |
| `last_track.title` | `string` | Track title |
| `last_track.posted_at` | `integer` | Unix timestamp of when the entry was posted |
| `last_error` | `string \| null` | Last error message, or `null` |
| `firmware_version` | `string` | Semantic version of the running firmware |
| `config_hash` | `string` | Short hash of the active runtime config (for detecting stale config) |
| `loop_max_ms` | `integer` | Maximum `loop()` duration since last heartbeat (performance metric) |
| `reconnect_count` | `integer` | Number of network reconnections since boot |
| `tracks_detected` | `integer` | Total track changes detected from AzuraCast since boot |
| `tracks_posted` | `integer` | Total entries successfully posted to the flowsheet since boot |
| `errors_since_boot` | `integer` | Total errors since boot |
| `button_press_count` | `integer` | Number of button presses since last heartbeat (WiFi fallback only; 0 if no presses) |

**Command** (Server → Arduino):

```json
{
    "type": "command",
    "id": "abc123",
    "action": "set_config",
    "key": "poll_interval_ms",
    "value": "30000"
}
```

| Field | Type | Description |
|---|---|---|
| `type` | `"command"` | Message discriminator |
| `id` | `string` | Unique command ID for acknowledgment correlation |
| `action` | `string` | One of: `set_config`, `pause`, `resume`, `end_show`, `restart`, `ping` |
| `key` | `string \| undefined` | Config key (only for `set_config`) |
| `value` | `string \| undefined` | Config value (only for `set_config`) |

**Acknowledgment** (Arduino → Server):

```json
{
    "type": "ack",
    "id": "abc123",
    "status": "ok"
}
```

| Field | Type | Description |
|---|---|---|
| `type` | `"ack"` | Message discriminator |
| `id` | `string` | The `id` from the command being acknowledged |
| `status` | `string` | One of: `ok`, `error`, `unknown_command` |
| `error` | `string \| undefined` | Error message (only when `status` is `"error"`) |

**Now Playing Relay** (Server → Arduino):

```json
{
    "type": "now_playing",
    "sh_id": 98765,
    "artist": "Yo La Tengo",
    "title": "Autumn Sweater",
    "album": "I Can Hear the Heart Beating as One",
    "is_live": false
}
```

| Field | Type | Description |
|---|---|---|
| `type` | `"now_playing"` | Message discriminator |
| `sh_id` | `integer` | AzuraCast song history ID |
| `artist` | `string` | Artist name |
| `title` | `string` | Track title |
| `album` | `string` | Album title |
| `is_live` | `boolean` | Whether a live DJ is streaming |

This is a flat structure designed for efficient ArduinoJson parsing. If the relay architecture is used ([Appendix B](#appendix-b-azuracast-centrifugo-integration-details)), the management server extracts these fields from AzuraCast's Centrifugo feed and sends this simplified format. If the Arduino subscribes directly to Centrifugo ([Section 3.9](#39-azuracast-centrifugo-direct-websocket), recommended), this message type is not used -- the Arduino parses the Centrifugo payload itself.

**Error Report** (Arduino → Server):

```json
{
    "type": "error",
    "level": "error",
    "module": "flowsheet_client",
    "code": "HTTP_TIMEOUT",
    "message": "POST /playlists/flowsheetEntryAdd timed out after 10000ms",
    "state": "AUTO_DJ_ACTIVE",
    "uptime_s": 86402,
    "free_ram": 524288,
    "count": 3
}
```

| Field | Type | Description |
|---|---|---|
| `type` | `"error"` | Message discriminator |
| `level` | `string` | One of: `warning`, `error`, `fatal` |
| `module` | `string` | Source module (e.g., `flowsheet_client`, `azuracast_client`, `network_manager`) |
| `code` | `string` | Error code (e.g., `HTTP_TIMEOUT`, `JSON_PARSE`, `WIFI_DISCONNECT`, `WS_DISCONNECT`, `TLS_HANDSHAKE`, `NTP_FAIL`) |
| `message` | `string` | Human-readable error description |
| `state` | `string` | State machine state when the error occurred |
| `uptime_s` | `integer` | Seconds since boot |
| `free_ram` | `integer` | Free heap bytes at time of error |
| `count` | `integer` | Number of times this error has occurred since last report |

Consecutive identical errors are batched on the Arduino side: `count` is incremented locally and the error report is sent periodically rather than on every occurrence. This avoids flooding the WebSocket with repeated errors (e.g., a flapping network connection). The management server can relay these to Sentry or another error tracking service, grouped by `module` and `code`.

**Button Toggle** (Arduino → Server):

```json
{
    "type": "button_toggle",
    "timestamp": 1709852100
}
```

| Field | Type | Description |
|---|---|---|
| `type` | `"button_toggle"` | Message discriminator |
| `timestamp` | `integer` | Unix timestamp of the button press (from NTP) |

Sent when the physical mushroom button is pressed ([Section 2.7](#27-activation-sources)). The orchestrator responds by toggling its activation state. The ack includes the resulting state:

```json
{
    "type": "ack",
    "id": "btn_1709852100",
    "status": "ok",
    "result": { "active": true }
}
```

The `result` field is an optional extension to the `AutoDJAck` schema. It is present only in acks for `button_toggle` messages. The Arduino uses `result.active` to update local state (e.g., status LED) but does not depend on it for state machine transitions. The `id` is derived from the button press timestamp for correlation.

#### 3.6.3 Supported Commands

| Action | Parameters | Effect | Hot-reload? |
|---|---|---|---|
| `set_config` | `key`, `value` | Write a config parameter to KVStore | Depends on key (see below) |
| `pause` | -- | Suspend flowsheet posting; state machine stays in IDLE | Yes |
| `resume` | -- | Resume normal operation | Yes |
| `end_show` | -- | Force-end the current show | Yes |
| `restart` | -- | Software reset via `NVIC_SystemReset()` | N/A |
| `ping` | -- | Arduino sends an immediate heartbeat in response | Yes |

#### 3.6.4 Hot-Reload Behavior

| Config key | Hot-reloadable? | Notes |
|---|---|---|
| `poll_interval_ms` | Yes | Takes effect on next poll cycle |
| `wifi_ssid` / `wifi_pass` | No | Requires restart (see below) |
| `api_key` | Yes | Takes effect on next HTTP request |
| `utc_offset` | Yes | Takes effect on next `currentHourMs()` call |
| `flowsheet_backend` | No | Obsolete (reporter model — the firmware writes no flowsheets) |

**Why `wifi_ssid` / `wifi_pass` require restart**: WiFi credentials are consumed by `WiFi.begin(ssid, password)` during the connection sequence. The WiFi module's firmware holds onto the credentials it was given at `begin()` -- updating the `RuntimeConfig` struct alone doesn't reconnect. Calling `WiFi.disconnect()` + `WiFi.begin()` with new credentials would block the `loop()` for up to 36 seconds (the Giga R1 firmware bug). A restart sequences this cleanly through the normal boot path. Since WiFi is only the fallback transport (Section 2.2), this is low-urgency.

**`flowsheet_backend`**: Obsolete under the reporter model. The firmware no longer writes flowsheets, so it has no flowsheet-backend selector. All flowsheet writes are performed by the orchestrator against Backend-Service. See [Section 2.3](#23-flowsheet-write-architecture).

#### 3.6.5 Keepalive Strategy

NAT gateways and campus firewalls kill idle TCP connections, typically after 60-300 seconds. The WebSocket must stay active:

- **Heartbeat interval (30s)** acts as an application-level keepalive. The server expects a heartbeat at least this often; absence triggers a "device offline" alert.
- **WebSocket ping/pong frames** as a transport-level keepalive. Most WebSocket libraries handle these automatically. If the server doesn't receive a pong within 10 seconds, it considers the connection dead.

### 3.7 HTTP Fallback: Management Polling (WiFi)

**Status**: Planned (Phase 3)

When the Arduino is on WiFi (no persistent connections), the management channel degrades to HTTP short polling on a 60-second interval.

**Heartbeat** (Arduino → Server):

| Field | Value |
|---|---|
| **Method** | POST |
| **URL** | `https://<management-server>/api/auto-dj/heartbeat` |
| **Auth** | `X-Auto-DJ-Key: <key>` |
| **Content-Type** | `application/json` |
| **Body** | Same JSON as the WebSocket heartbeat message ([Section 3.6.2](#362-message-types)). The `button_press_count` field carries any button presses that occurred since the last heartbeat; the orchestrator toggles state if the count is odd. |
| **Response** | 200 OK |

**Command poll** (Arduino → Server):

| Field | Value |
|---|---|
| **Method** | GET |
| **URL** | `https://<management-server>/api/auto-dj/commands` |
| **Auth** | `X-Auto-DJ-Key: <key>` |
| **Response** | 200 JSON array of pending commands, or empty array |

The Arduino processes each command and sends acknowledgments as separate POST requests.

### 3.8 Server-Side Endpoints

| Method | Path | Purpose | Auth | Transport |
|---|---|---|---|---|
| `GET` (upgrade) | `/api/auto-dj/ws` | WebSocket management channel | `X-Auto-DJ-Key` | Ethernet primary |
| `POST` | `/api/auto-dj/heartbeat` | Heartbeat (fallback) | `X-Auto-DJ-Key` | WiFi fallback |
| `GET` | `/api/auto-dj/commands` | Command poll (fallback) | `X-Auto-DJ-Key` | WiFi fallback |
| `POST` | `/api/auto-dj/commands` | Admin enqueues a command | Better Auth session/JWT | Admin UI |
| `GET` | `/api/auto-dj/status` | Latest heartbeat + connection state | Better Auth session/JWT | Admin UI |

All Arduino-facing endpoints authenticate via the `X-Auto-DJ-Key` header. All admin-facing endpoints authenticate via Better Auth session cookies or JWT.

### 3.9 AzuraCast Centrifugo: Direct WebSocket

**Status**: Planned (Phase 2/3)

AzuraCast embeds a [Centrifugo](https://centrifugal.dev/) real-time messaging server and exposes a public WebSocket endpoint for now-playing updates. The Arduino can subscribe directly -- no relay server needed.

#### 3.9.1 Protocol

| Field | Value |
|---|---|
| **Endpoint** | `wss://remote.wxyc.org/api/live/nowplaying/websocket` |
| **Auth** | None (public, no token required) |
| **Transport** | Ethernet only (persistent WebSocket) |
| **Fallback** | HTTP polling ([Section 3.2](#32-outbound-http-azuracast-now-playing)) over WiFi or when WebSocket is unavailable |

**Connection sequence**:

```mermaid
sequenceDiagram
    participant Arduino
    participant AZ as "AzuraCast (Centrifugo)"

    Arduino->>AZ: WebSocket upgrade<br/>(wss://remote.wxyc.org/api/live/nowplaying/websocket)
    AZ-->>Arduino: 101 Switching Protocols

    Arduino->>AZ: {"subs": {"station:shortcode": {"recover": true}}}
    AZ-->>Arduino: {"connect": {"subs": {"station:shortcode": {"publications": [...]}}}}
    Note right of Arduino: Initial cached now-playing<br/>data received immediately

    AZ->>Arduino: {"channel": "station:shortcode", "pub": {"data": {"np": {...}}}}
    Note right of Arduino: Track change:<br/>new sh_id detected

    Note over Arduino,AZ: Connection lost

    Arduino->>AZ: WebSocket reconnect<br/>(exponential backoff: 1s, 2s, 4s, ... 60s cap)
    AZ-->>Arduino: 101 Switching Protocols
    Arduino->>AZ: {"subs": {"station:shortcode": {"recover": true}}}
    AZ-->>Arduino: Missed publications replayed
    Note right of Arduino: recover: true replays<br/>messages missed during disconnect
```

The `recover: true` flag enables Centrifugo's connection recovery -- on reconnect, the server replays messages missed during the disconnection window. The station shortcode must be verified -- see [Open Question 9](#8-open-questions).

**Relevant fields in `np`**:

| JSON Path | Type | Arduino Usage |
|---|---|---|
| `np.now_playing.sh_id` | `int` | Track change detection (same as HTTP polling) |
| `np.now_playing.song.artist` | `string` | Flowsheet entry |
| `np.now_playing.song.title` | `string` | Flowsheet entry |
| `np.now_playing.song.album` | `string` | Flowsheet entry |
| `np.live.is_live` | `bool` | Live DJ detection |

These are the same fields extracted by the HTTP polling endpoint ([Section 3.2](#32-outbound-http-azuracast-now-playing)). The ArduinoJson filter document is identical.

**Sources**: [AzuraCast Now Playing Data APIs](https://www.azuracast.com/docs/developers/now-playing-data/), [AzuraCast HPNP SSE example](https://gist.github.com/Moonbase59/d42f411e10aff6dc58694699010307aa)

#### 3.9.2 Dual-Mode Architecture

```mermaid
stateDiagram-v2
    [*] --> PollMode: Boot

    state PollMode {
        [*] --> Polling
        Polling: Arduino polls AzuraCast HTTP API<br>GET /api/nowplaying_static/main.json<br>every POLL_INTERVAL_MS (20s)
    }

    state PushMode {
        [*] --> Listening
        Listening: Arduino receives now_playing<br>via direct Centrifugo WebSocket<br>near-real-time updates
        Listening --> SafetyPoll: 60s since last push
        SafetyPoll: Arduino polls AzuraCast HTTP API<br>as a safety net
        SafetyPoll --> Listening: WebSocket message received
    }

    PollMode --> PushMode: Ethernet up +<br>WebSocket connected
    PushMode --> PollMode: WebSocket disconnected /<br>Ethernet lost
```

- **Ethernet (push mode)**: The Arduino opens a WebSocket directly to AzuraCast's Centrifugo endpoint. Track updates arrive in near-real-time. A 60-second safety-net poll to the HTTP API catches any missed messages (Centrifugo is best-effort; the HTTP endpoint is Nginx-cached and authoritative).
- **WiFi (poll mode)**: The Arduino polls the AzuraCast HTTP API on the existing `POLL_INTERVAL_MS` timer. No persistent connections (to avoid the Giga R1 crash bug). No change from current behavior.

#### 3.9.3 Why Direct (Not Relayed)

The original design (see [Appendix B](#appendix-b-azuracast-centrifugo-integration-details)) assumed the Arduino could not subscribe to Centrifugo directly, requiring the management server to act as a relay. This assumption was wrong: AzuraCast's Centrifugo endpoint uses standard WebSocket with a simple JSON subscription message and no authentication. The Arduino can connect directly using the [`ArduinoWebsockets`](https://github.com/gilmaimon/ArduinoWebsockets) library.

Direct subscription is simpler:

| | Direct (recommended) | Relay via management server |
|--|---|---|
| **Dependencies** | Arduino + AzuraCast only | Arduino + management server + AzuraCast |
| **Latency** | Single hop | Two hops (Centrifugo → server → Arduino) |
| **Failure modes** | AzuraCast down | AzuraCast down OR management server down |
| **Phase dependency** | Phase 2 (Ethernet) | Phase 3 (management server) |
| **Arduino complexity** | WebSocket client + JSON parsing | Same (receives JSON either way) |

The relay architecture remains a fallback option if direct connection proves problematic (e.g., ArduinoJson memory limits on the full Centrifugo payload, or reconnection complexity). The management server can always be interposed later without changing the Arduino's internal data flow -- the `AzuraCastClient` consumes the same fields regardless of source.

#### 3.9.4 ArduinoJson Memory Considerations

The Centrifugo now-playing payload is larger than the static HTTP endpoint response (~10 KB) because it includes the full Centrifugo envelope. An ArduinoJson filter document keeps memory usage bounded:

```cpp
JsonDocument filter;
filter["connect"]["subs"]["station:*"]["publications"][0]["data"]["np"]["now_playing"]["sh_id"] = true;
filter["connect"]["subs"]["station:*"]["publications"][0]["data"]["np"]["now_playing"]["song"]["artist"] = true;
filter["connect"]["subs"]["station:*"]["publications"][0]["data"]["np"]["now_playing"]["song"]["title"] = true;
filter["connect"]["subs"]["station:*"]["publications"][0]["data"]["np"]["now_playing"]["song"]["album"] = true;
filter["connect"]["subs"]["station:*"]["publications"][0]["data"]["np"]["live"]["is_live"] = true;
// Same filter pattern for "pub" messages
```

If the Centrifugo payload exceeds ArduinoJson's practical parsing limits on the Giga R1 (~16 KB with filter), the relay approach ([Appendix B](#appendix-b-azuracast-centrifugo-integration-details)) becomes necessary -- the management server would extract the relevant fields and send a flat ~200-byte `AutoDJNowPlaying` message.

See [Appendix B](#appendix-b-azuracast-centrifugo-integration-details) for the relay alternative and detailed Centrifugo integration notes.

### 3.10 Virtual Switch API

**Status**: Planned

The orchestrator ([auto-dj-orchestrator](https://github.com/WXYC/auto-dj-orchestrator)) exposes these endpoints for [dj-site](https://github.com/WXYC/dj-site) (and any future admin UI) to control auto-DJ activation. These are separate from the device management endpoints in [Section 3.8](#38-server-side-endpoints), which are Arduino-facing. These endpoints are included in this networking spec because this document is the single source of truth for all auto-DJ network traffic, and the orchestrator README explicitly references it.

#### 3.10.1 Traffic Summary

| # | Direction | Protocol | Endpoint | Auth | Content Type | Status |
|---|---|---|---|---|---|---|
| 16 | dj-site → Orchestrator | HTTPS POST | `/api/auto-dj/activate` | Better Auth JWT | JSON | Planned |
| 17 | dj-site → Orchestrator | HTTPS POST | `/api/auto-dj/deactivate` | Better Auth JWT | JSON | Planned |
| 18 | dj-site → Orchestrator | HTTPS GET | `/api/auto-dj/status` | Better Auth JWT | JSON response | Planned |

#### 3.10.2 Activate

| Field | Value |
|---|---|
| **Method** | POST |
| **URL** | `https://<orchestrator>/api/auto-dj/activate` |
| **Auth** | `Authorization: Bearer <JWT>` (Better Auth, `dj` role or higher) |
| **Request body** | None |
| **Response (200)** | `AutoDJStatus` JSON (see below) |

Activates the auto-DJ system. The orchestrator starts a show on Backend-Service and begins subscribing to AzuraCast for track changes.

**Error responses**:
- `409 Conflict`: Auto-DJ is already active. Response body includes the current `AutoDJStatus`.
- `409 Conflict`: A live DJ show is in progress. Auto-DJ cannot activate while a DJ is broadcasting.
- `403 Forbidden`: Insufficient permissions.

**Side effects**:
- Orchestrator calls `POST /flowsheet/join` on Backend-Service to create a show.
- Orchestrator begins subscribing to AzuraCast now-playing feed.
- If the Arduino is connected via the management channel, the orchestrator sends it a `resume` command (in case it was paused).

#### 3.10.3 Deactivate

| Field | Value |
|---|---|
| **Method** | POST |
| **URL** | `https://<orchestrator>/api/auto-dj/deactivate` |
| **Auth** | `Authorization: Bearer <JWT>` (Better Auth, `dj` role or higher) |
| **Request body** | None |
| **Response (200)** | `AutoDJDeactivateResponse` JSON (see below) |

Deactivates the auto-DJ system. The orchestrator ends the current show and stops writing to the flowsheet.

**Error responses**:
- `409 Conflict`: Auto-DJ is not currently active.
- `403 Forbidden`: Insufficient permissions.

**Side effects**:
- Orchestrator calls `POST /flowsheet/end` on Backend-Service.
- Orchestrator stops subscribing to AzuraCast.
- If the Arduino is connected, the orchestrator sends it a `pause` command.

#### 3.10.4 Status

| Field | Value |
|---|---|
| **Method** | GET |
| **URL** | `https://<orchestrator>/api/auto-dj/status` |
| **Auth** | `Authorization: Bearer <JWT>` (Better Auth, `dj` role or higher for full status) |
| **Response (200)** | `AutoDJStatus` JSON |

Returns the current auto-DJ activation state, current track, and device status.

**Response when active:**

```json
{
    "active": true,
    "activatedBy": {
        "source": "virtual_switch",
        "userId": "usr_abc123",
        "userName": "DJ Moonbeam"
    },
    "activatedAt": "2026-03-07T22:15:00Z",
    "showId": 789,
    "currentTrack": {
        "artist": "Juana Molina",
        "title": "la paradoja",
        "album": "DOGA",
        "detectedAt": "2026-03-07T23:42:18Z"
    },
    "device": {
        "online": true,
        "transport": "ethernet",
        "lastHeartbeat": "2026-03-07T23:44:30Z",
        "relayState": "auto_dj_active"
    }
}
```

**Response when inactive:**

```json
{
    "active": false,
    "lastDeactivatedAt": "2026-03-07T20:00:00Z",
    "lastDeactivatedBy": {
        "source": "relay",
        "detail": "Live DJ detected"
    },
    "device": {
        "online": true,
        "transport": "ethernet",
        "lastHeartbeat": "2026-03-07T23:44:30Z",
        "relayState": "dj_live"
    }
}
```

The `device` block is `null` if the Arduino has never connected to the orchestrator.

| Field | Type | Description |
|---|---|---|
| `active` | `boolean` | Whether auto-DJ is currently active |
| `activatedBy` | `object \| undefined` | Present when active. `source` is one of `"virtual_switch"`, `"button"`, `"relay"` |
| `activatedBy.userId` | `string \| undefined` | Better Auth user ID (only for `virtual_switch` source) |
| `activatedBy.userName` | `string \| undefined` | Display name (only for `virtual_switch` source) |
| `activatedAt` | `string \| undefined` | ISO 8601 timestamp of activation |
| `showId` | `integer \| undefined` | Active flowsheet show ID |
| `currentTrack` | `object \| null` | Current track from AzuraCast, or `null` if no track detected yet |
| `lastDeactivatedAt` | `string \| undefined` | Present when inactive. ISO 8601 timestamp of last deactivation |
| `lastDeactivatedBy` | `object \| undefined` | Present when inactive. Same `source` field as `activatedBy` |
| `device` | `object \| null` | Arduino device status, or `null` if never connected |
| `device.online` | `boolean` | Whether the Arduino is currently connected (heartbeat within 60s) |
| `device.transport` | `string` | `"ethernet"` or `"wifi"` |
| `device.lastHeartbeat` | `string` | ISO 8601 timestamp of last heartbeat |
| `device.relayState` | `string` | `"auto_dj_active"` or `"dj_live"` |

---

## 4. Authentication and Credentials

### 4.1 Credential Inventory

| Credential | Stored in | Authenticates to | Rotation frequency |
|---|---|---|---|
| WiFi password (`WIFI_PASS`) | [`secrets.h`](../auto-dj-arduino-switch/secrets.h.example) (compile-time), KVStore (runtime, after Phase 1) | UNC-PSK WiFi network | Annually (UNC policy) |
| Orchestrator management-channel key (`AUTO_DJ_KEY`) | `secrets.h` (compile-time), KVStore (runtime, after Phase 1) | Orchestrator management channel (WebSocket upgrade + HTTP fallback), sent as the `X-Auto-DJ-Key` header | Manual (operator-initiated) |

Under the reporter model the firmware holds only these two credentials. The pre-re-architecture firmware also carried a tubafrenzy API key (the same `X-Auto-DJ-Key` value) for direct tubafrenzy writes; that credential and its write path have been removed. The Arduino has no Backend-Service credentials. All Backend-Service communication is delegated to the [auto-dj-orchestrator](https://github.com/WXYC/auto-dj-orchestrator), which authenticates as a service identity using JWT with standard token refresh (see [unified-auth-system.md](https://github.com/WXYC/docs/blob/main/unified-auth-system.md)).

### 4.2 tubafrenzy Authentication (historical)

**Status**: Removed from the firmware in the reporter re-architecture (`flowsheet_client.cpp` was deleted). The firmware no longer authenticates to tubafrenzy. The description below is historical: it documents how the pre-re-architecture firmware authenticated its (now-removed) tubafrenzy writes and how tubafrenzy validated the key.

Historically, the Arduino authenticated to tubafrenzy by sending the `X-Auto-DJ-Key` header with every request. The server validated this via `XYCCatalogServlet.isAutoDJRequest()`:

```java
protected boolean isAutoDJRequest(HttpServletRequest request) {
    String apiKey = getAutoDJApiKey();  // System.getenv("AUTO_DJ_API_KEY")
    if (apiKey == null || apiKey.isEmpty()) {
        return false;
    }
    String headerKey = request.getHeader("X-Auto-DJ-Key");
    if (headerKey == null) {
        return false;
    }
    return MessageDigest.isEqual(
        apiKey.getBytes(StandardCharsets.UTF_8),
        headerKey.getBytes(StandardCharsets.UTF_8)
    );
}
```

Key details:

- **Timing-safe comparison**: `MessageDigest.isEqual()` is constant-time, preventing timing attacks.
- **Server-side config**: The `AUTO_DJ_API_KEY` environment variable on the tubafrenzy server (wxyc.info) must match the value in the Arduino's `secrets.h`.
- **Bypass of IP check**: A valid `X-Auto-DJ-Key` bypasses the normal control-room IP address check in `validateControlRoomAccess()`.

### 4.3 Backend-Service Authentication (Delegated to Orchestrator)

**Status**: Planned (orchestrator responsibility)

The Arduino does not authenticate to Backend-Service directly. All Backend-Service communication is delegated to the [auto-dj-orchestrator](https://github.com/WXYC/auto-dj-orchestrator), which authenticates as a service identity (`auto-dj-orchestrator@services.wxyc.org`) using standard JWT refresh — sign in at startup, cache token, refresh before expiry.

This eliminates the PAT vs JWT conflict: the Arduino's constrained environment cannot perform JWT refresh, but the orchestrator (a server-side Node.js service) handles it naturally. Under the reporter model the Arduino's credential inventory is just the WiFi password and the orchestrator management-channel key.

#### Orchestrator service account set-up (one-time, by an admin)

1. **Create a better-auth user** for the orchestrator (email: `auto-dj-orchestrator@services.wxyc.org`, role: `auto-dj-orchestrator`). This is a service identity with scoped permissions (`flowsheet: read, write`) declared in `ServiceRoles`.

2. **Register a DJ record** via `POST /djs/register` with:
   - `dj_name`: `"Auto DJ"`
   - `is_automation`: `true`
   - Backend-Service resolves the Auto DJ's `dj_id` server-side from the service identity — the orchestrator never supplies it.

3. **Add `is_automation` to the `DJ` and `NewDJ` schemas in `api.yaml`**:
   - Type: `boolean`
   - Default: `false`
   - Purpose: Lets admin UIs filter automation DJs from human DJs without Backend-Service-specific logic. The column is part of the public schema and will propagate to all generated types.

See [unified-auth-system.md Section 8](https://github.com/WXYC/docs/blob/main/unified-auth-system.md#8-service-to-service-authentication) for the full orchestrator auth flow.

### 4.4 Management Server Auth (Arduino-Facing)

The Arduino authenticates to the management server using the same `X-Auto-DJ-Key` header used for tubafrenzy. This applies to:

- WebSocket upgrade request (`wss://server/api/auto-dj/ws`)
- HTTP fallback heartbeat (`POST /api/auto-dj/heartbeat`)
- HTTP fallback command poll (`GET /api/auto-dj/commands`)

The management server validates the key using the same timing-safe comparison pattern.

### 4.5 Management Server Auth (Admin-Facing)

Admin-facing endpoints (`POST /api/auto-dj/commands`, `GET /api/auto-dj/status`) authenticate via Better Auth session cookies or JWT. `stationManager`+ can issue operational commands (pause/resume/status); `superAdmin` is required for infrastructure operations (credential rotation, config push). See [unified-auth-system.md Section 8](https://github.com/WXYC/docs/blob/main/unified-auth-system.md#orchestrator-admin-endpoint-access-matrix) for the full access matrix.

### 4.6 Credential Rotation Protocol

With Ethernet as the primary transport, credential rotation is significantly less risky. The Ethernet connection does not use credentials that rotate externally (no WiFi password, no PSK).

#### Ethernet mitigates the chicken-and-egg problem

```mermaid
flowchart LR
    subgraph Before["WiFi-Only (old design)"]
        direction TB
        B1["UNC changes PSK"]
        B2["Arduino loses WiFi"]
        B3["No transport available"]
        B4["Device bricked"]
        B1 --> B2 --> B3 --> B4
    end

    subgraph After["Ethernet Primary (new design)"]
        direction TB
        A1["UNC changes PSK"]
        A2["WiFi fallback breaks"]
        A3["Ethernet still connected"]
        A4["Push new password<br>over WebSocket"]
        A5["WiFi fallback restored"]
        A1 --> A2 --> A3 --> A4 --> A5
    end
```

The only scenario that still requires physical access is if **both** the Ethernet jack goes dead **and** the WiFi password is stale.

#### API key rotation steps

1. Generate a new API key.
2. Update the server-side env var (e.g., `AUTO_DJ_API_KEY` on tubafrenzy) to accept **both** old and new keys temporarily.
3. Push the new key to the Arduino via `set_config` (over WebSocket or HTTP fallback).
4. After the Arduino acknowledges, remove the old key from the server.

```mermaid
sequenceDiagram
    participant Admin
    participant Server as "tubafrenzy / Mgmt Server"
    participant Arduino

    Admin->>Server: Update AUTO_DJ_API_KEY env<br/>to accept old + new
    Note over Server: Both keys valid temporarily

    Admin->>Server: POST /api/auto-dj/commands<br/>{"action": "set_config",<br/>"key": "api_key", "value": "new-key"}
    Server->>Arduino: {"type": "command",<br/>"action": "set_config",<br/>"key": "api_key", "value": "new-key"}
    Arduino->>Arduino: Write new key to KVStore
    Arduino->>Server: {"type": "ack", "status": "ok"}
    Server-->>Admin: Command acknowledged

    Admin->>Server: Remove old key from env
    Note over Server: Only new key valid
```

#### Backend-Service token rotation

Not applicable to the Arduino. The orchestrator manages its own JWT refresh cycle (sign in at startup, refresh before expiry). Credential rotation for the orchestrator's service account is handled through better-auth's standard password reset flow, not through the Arduino's management channel.

### 4.7 Credential Fallback and Recovery

The firmware keeps **both** the KVStore credential and the compile-time default. On connection failure after N attempts with the stored credential, it falls back to the compile-time default:

```cpp
// Pseudocode
if (!connectWith(kvstore.wifi_pass, MAX_ATTEMPTS)) {
    Serial.println("[WiFi] Stored credential failed, trying compiled default");
    if (!connectWith(WIFI_PASS_DEFAULT, MAX_ATTEMPTS)) {
        Serial.println("[WiFi] Both credentials failed");
    }
}
```

This ensures that a bad credential push doesn't permanently brick the WiFi fallback -- a firmware reflash with the correct default can always restore access.

### 4.8 Security Considerations

- **Transport security**: All communication is over TLS (BearSSL via `SSLClient` on Ethernet, `WiFiSSLClient` on WiFi). Credentials are encrypted in transit.
- **Storage security**: KVStore writes to flash in plaintext. An attacker with physical access to the board could read the flash. This is acceptable -- physical access to the studio already implies access to the mixing board, network, and everything else.
- **Command authentication**: Commands are authenticated by the `X-Auto-DJ-Key` header (management server and tubafrenzy). A compromised key would allow unauthorized actions. Key rotation ([Section 4.6](#46-credential-rotation-protocol)) mitigates this.
- **Command validation**: The Arduino must validate all command payloads. Reject unknown actions, enforce maximum string lengths, and never execute arbitrary code from the server.

---

## 5. wxyc-shared Type Specification

### 5.1 Current Code Generation Pipeline

The `api.yaml` file in `wxyc-shared` is the single source of truth for API types. Code generation produces:

- **TypeScript** ([`openapi-generator-cli`](https://openapi-generator.tech/) → `src/generated/models/`): consumed by Backend-Service, dj-site, management server, admin UI
- **Python** ([`datamodel-codegen`](https://github.com/koxudaxi/datamodel-code-generator) → Pydantic v2): consumed by [request-o-matic](https://github.com/WXYC/request-o-matic), [library-metadata-lookup](https://github.com/WXYC/library-metadata-lookup)
- **Swift**: consumed by [wxyc-ios-64](https://github.com/WXYC/wxyc-ios-64) (via existing code generation pipeline)
- **Kotlin**: consumed by [WXYC-Android](https://github.com/WXYC/WXYC-Android) (via existing code generation pipeline)

The [`tsup`](https://tsup.egoist.dev/) build produces independently importable entry points:

| Entry point | Import path | Contents |
|---|---|---|
| `src/index.ts` | `@wxyc/shared` | Root re-exports |
| `src/dtos/index.ts` | `@wxyc/shared/dtos` | DTOs + extensions (unions, type guards) |
| `src/auth-client/index.ts` | `@wxyc/shared/auth-client` | Auth client (React "use client") |
| `src/auth-client/auth.ts` | `@wxyc/shared/auth-client/auth` | Pure auth (server-side, no React) |
| `src/validation/index.ts` | `@wxyc/shared/validation` | Validation schemas |
| `src/test-utils/index.ts` | `@wxyc/shared/test-utils` | Test utilities |

Breaking change detection: `scripts/check-breaking-changes.js` compares the generated types against the previous version.

### 5.2 New Types for api.yaml

The following OpenAPI 3.0 schema blocks are designed to be added to `api.yaml` under `components/schemas`. They formalize the WebSocket message types from [Section 3.6.2](#362-message-types).

#### 5.2.1 WebSocket Message Envelope

```yaml
AutoDJWebSocketMessage:
  oneOf:
    - $ref: '#/components/schemas/AutoDJHeartbeat'
    - $ref: '#/components/schemas/AutoDJCommand'
    - $ref: '#/components/schemas/AutoDJAck'
    - $ref: '#/components/schemas/AutoDJNowPlaying'
    - $ref: '#/components/schemas/AutoDJErrorReport'
    - $ref: '#/components/schemas/AutoDJButtonToggle'
  discriminator:
    propertyName: type
    mapping:
      heartbeat: '#/components/schemas/AutoDJHeartbeat'
      command: '#/components/schemas/AutoDJCommand'
      ack: '#/components/schemas/AutoDJAck'
      now_playing: '#/components/schemas/AutoDJNowPlaying'
      error: '#/components/schemas/AutoDJErrorReport'
      button_toggle: '#/components/schemas/AutoDJButtonToggle'
```

#### 5.2.2 AutoDJHeartbeat

```yaml
AutoDJHeartbeat:
  type: object
  required:
    - type
    - state
    - transport
    - uptime_s
    - free_ram
    - firmware_version
    - config_hash
    - loop_max_ms
    - reconnect_count
    - tracks_detected
    - tracks_posted
    - errors_since_boot
  properties:
    type:
      type: string
      enum: [heartbeat]
    state:
      type: string
      enum: [BOOTING, CONNECTING, CONNECTED, ERROR_STATE]  # reporter firmware: connectivity states only
    transport:
      type: string
      enum: [ethernet, wifi]
    uptime_s:
      type: integer
    wifi_rssi:
      type: integer
      nullable: true
    free_ram:
      type: integer
    radio_show_id:
      type: integer
      nullable: true
    last_track:
      $ref: '#/components/schemas/AutoDJLastTrack'
    last_error:
      type: string
      nullable: true
    firmware_version:
      type: string
    config_hash:
      type: string
    loop_max_ms:
      type: integer
    reconnect_count:
      type: integer
    tracks_detected:
      type: integer
    tracks_posted:
      type: integer
    errors_since_boot:
      type: integer
    button_press_count:
      type: integer
      description: Number of button presses since last heartbeat (WiFi fallback; 0 if none)

AutoDJLastTrack:
  type: object
  required:
    - artist
    - title
    - posted_at
  properties:
    artist:
      type: string
    title:
      type: string
    posted_at:
      type: integer
      description: Unix timestamp
```

#### 5.2.3 AutoDJCommand

```yaml
AutoDJCommand:
  type: object
  required:
    - type
    - id
    - action
  properties:
    type:
      type: string
      enum: [command]
    id:
      type: string
      description: Unique command ID for ack correlation
    action:
      $ref: '#/components/schemas/AutoDJCommandAction'
    key:
      type: string
      description: Config key (only for set_config)
    value:
      type: string
      description: Config value (only for set_config)
```

#### 5.2.4 AutoDJAck

```yaml
AutoDJAck:
  type: object
  required:
    - type
    - id
    - status
  properties:
    type:
      type: string
      enum: [ack]
    id:
      type: string
      description: The id from the command being acknowledged
    status:
      type: string
      enum: [ok, error, unknown_command]
    error:
      type: string
      description: Error message (only when status is error)
    result:
      type: object
      description: Optional result data (e.g., { active: boolean } for button_toggle acks)
```

#### 5.2.5 AutoDJNowPlaying

```yaml
AutoDJNowPlaying:
  type: object
  required:
    - type
    - sh_id
    - artist
    - title
    - album
    - is_live
  properties:
    type:
      type: string
      enum: [now_playing]
    sh_id:
      type: integer
      description: AzuraCast song history ID
    artist:
      type: string
    title:
      type: string
    album:
      type: string
    is_live:
      type: boolean
      description: Whether a live DJ is streaming
```

#### 5.2.6 AutoDJErrorReport

```yaml
AutoDJErrorReport:
  type: object
  required:
    - type
    - level
    - module
    - code
    - message
    - state
    - uptime_s
    - free_ram
    - count
  properties:
    type:
      type: string
      enum: [error]
    level:
      $ref: '#/components/schemas/AutoDJErrorLevel'
    module:
      type: string
      description: Source module (e.g., flowsheet_client, azuracast_client)
    code:
      $ref: '#/components/schemas/AutoDJErrorCode'
    message:
      type: string
    state:
      type: string
      enum: [BOOTING, CONNECTING, CONNECTED, ERROR_STATE]  # reporter firmware: connectivity states only
    uptime_s:
      type: integer
    free_ram:
      type: integer
    count:
      type: integer
      description: Occurrences since last report

AutoDJErrorLevel:
  type: string
  enum: [warning, error, fatal]

AutoDJErrorCode:
  type: string
  enum:
    - HTTP_TIMEOUT
    - JSON_PARSE
    - WIFI_DISCONNECT
    - WS_DISCONNECT
    - TLS_HANDSHAKE
    - NTP_FAIL
    - KVSTORE_WRITE
    - FLOWSHEET_POST
    - AZURACAST_POLL
```

#### 5.2.7 AutoDJDeviceStatus

For the admin API -- aggregates the latest heartbeat with connection state and device identity.

```yaml
AutoDJDeviceStatus:
  type: object
  required:
    - connected
    - transport
    - last_heartbeat_at
    - firmware_version
  properties:
    connected:
      type: boolean
    transport:
      type: string
      enum: [ethernet, wifi, none]
    last_heartbeat_at:
      type: string
      format: date-time
      nullable: true
    last_heartbeat:
      $ref: '#/components/schemas/AutoDJHeartbeat'
    pending_commands:
      type: integer
      description: Number of unacknowledged commands in the queue
    firmware_version:
      type: string
    device_id:
      type: string
      description: MAC address or other unique identifier
```

#### 5.2.8 AutoDJCommandAction Enum

```yaml
AutoDJCommandAction:
  type: string
  enum:
    - set_config
    - pause
    - resume
    - end_show
    - restart
    - ping
```

#### 5.2.9 AutoDJButtonToggle

```yaml
AutoDJButtonToggle:
  type: object
  required:
    - type
    - timestamp
  properties:
    type:
      type: string
      enum: [button_toggle]
    timestamp:
      type: integer
      description: Unix timestamp of the button press (from NTP)
```

#### 5.2.10 AutoDJStatus (Virtual Switch API)

Response type for `GET /api/auto-dj/status` and `POST /api/auto-dj/activate` ([Section 3.10](#310-virtual-switch-api)).

```yaml
AutoDJStatus:
  type: object
  required:
    - active
  properties:
    active:
      type: boolean
    activatedBy:
      $ref: '#/components/schemas/AutoDJActivationSource'
    activatedAt:
      type: string
      format: date-time
    showId:
      type: integer
    currentTrack:
      $ref: '#/components/schemas/AutoDJCurrentTrack'
      nullable: true
    lastDeactivatedAt:
      type: string
      format: date-time
    lastDeactivatedBy:
      $ref: '#/components/schemas/AutoDJActivationSource'
    device:
      $ref: '#/components/schemas/AutoDJDeviceSummary'
      nullable: true

AutoDJActivationSource:
  type: object
  required:
    - source
  properties:
    source:
      type: string
      enum: [virtual_switch, button, relay]
    userId:
      type: string
      description: Better Auth user ID (only for virtual_switch source)
    userName:
      type: string
      description: Display name (only for virtual_switch source)
    detail:
      type: string
      description: Additional context (e.g., "Live DJ detected" for relay source)

AutoDJCurrentTrack:
  type: object
  required:
    - artist
    - title
    - album
    - detectedAt
  properties:
    artist:
      type: string
    title:
      type: string
    album:
      type: string
    detectedAt:
      type: string
      format: date-time

AutoDJDeviceSummary:
  type: object
  required:
    - online
    - transport
    - lastHeartbeat
    - relayState
  properties:
    online:
      type: boolean
    transport:
      type: string
      enum: [ethernet, wifi]
    lastHeartbeat:
      type: string
      format: date-time
    relayState:
      type: string
      enum: [auto_dj_active, dj_live]
```

#### 5.2.11 AutoDJDeactivateResponse

Response type for `POST /api/auto-dj/deactivate` ([Section 3.10](#310-virtual-switch-api)).

```yaml
AutoDJDeactivateResponse:
  type: object
  required:
    - active
    - deactivatedBy
    - deactivatedAt
  properties:
    active:
      type: boolean
      enum: [false]
    deactivatedBy:
      $ref: '#/components/schemas/AutoDJActivationSource'
    deactivatedAt:
      type: string
      format: date-time
```

### 5.3 TypeScript Extensions

The new schemas live in `api.yaml` as `components/schemas` and are code-generated into `src/generated/models/`. Hand-written TypeScript utilities go in a new `src/auto-dj/` directory, following the pattern of `src/dtos/extensions.ts`.

#### New files

**`src/auto-dj/extensions.ts`**:

```typescript
import type {
    AutoDJHeartbeat,
    AutoDJCommand,
    AutoDJAck,
    AutoDJNowPlaying,
    AutoDJErrorReport,
    AutoDJButtonToggle,
} from '../generated/models';

// Discriminated union of all WebSocket message types
export type AutoDJWebSocketMessage =
    | AutoDJHeartbeat
    | AutoDJCommand
    | AutoDJAck
    | AutoDJNowPlaying
    | AutoDJErrorReport
    | AutoDJButtonToggle;

// Type guards
export function isHeartbeat(msg: AutoDJWebSocketMessage): msg is AutoDJHeartbeat {
    return msg.type === 'heartbeat';
}

export function isCommand(msg: AutoDJWebSocketMessage): msg is AutoDJCommand {
    return msg.type === 'command';
}

export function isAck(msg: AutoDJWebSocketMessage): msg is AutoDJAck {
    return msg.type === 'ack';
}

export function isNowPlaying(msg: AutoDJWebSocketMessage): msg is AutoDJNowPlaying {
    return msg.type === 'now_playing';
}

export function isErrorReport(msg: AutoDJWebSocketMessage): msg is AutoDJErrorReport {
    return msg.type === 'error';
}

export function isButtonToggle(msg: AutoDJWebSocketMessage): msg is AutoDJButtonToggle {
    return msg.type === 'button_toggle';
}
```

**`src/auto-dj/index.ts`**:

```typescript
// Re-export generated schemas
export type {
    AutoDJHeartbeat,
    AutoDJCommand,
    AutoDJAck,
    AutoDJNowPlaying,
    AutoDJErrorReport,
    AutoDJButtonToggle,
    AutoDJDeviceStatus,
    AutoDJCommandAction,
    AutoDJErrorLevel,
    AutoDJErrorCode,
    AutoDJLastTrack,
    AutoDJStatus,
    AutoDJActivationSource,
    AutoDJCurrentTrack,
    AutoDJDeviceSummary,
    AutoDJDeactivateResponse,
    AutoDJWebSocketMessage as AutoDJWebSocketMessageSchema,
} from '../generated/models';

// Re-export extensions (union type + type guards)
export {
    type AutoDJWebSocketMessage,
    isHeartbeat,
    isCommand,
    isAck,
    isNowPlaying,
    isErrorReport,
    isButtonToggle,
} from './extensions';
```

**New entry point** in `tsup.config.ts`:

```typescript
// Add to the entry array:
'src/auto-dj/index.ts'
```

**New export** in `package.json`:

```json
"./auto-dj": {
    "import": "./dist/auto-dj/index.js",
    "types": "./dist/auto-dj/index.d.ts"
}
```

Consumers import via `@wxyc/shared/auto-dj`.

### 5.4 Arduino Contract

The Arduino cannot consume npm packages. ArduinoJson code must manually match the schemas defined in `api.yaml`. This is a manual contract, not an automated import.

**Rule**: If you change a schema in `api.yaml`, you must update the corresponding ArduinoJson filter documents and struct definitions in the Arduino code.

| api.yaml Schema | Arduino File | What to Update |
|---|---|---|
| `AutoDJHeartbeat` | `management_client.cpp` | `sendHeartbeat()` JSON construction |
| `AutoDJCommand` | `management_client.cpp` | `processCommand()` JSON parsing + filter document |
| `AutoDJAck` | `management_client.cpp` | `sendAck()` JSON construction |
| `AutoDJNowPlaying` | `management_client.cpp` | `processNowPlaying()` JSON parsing + filter document |
| `AutoDJErrorReport` | `management_client.cpp` | `sendError()` JSON construction |
| (AzuraCast response) | `azuracast_client.cpp` | `poll()` filter document: `now_playing.sh_id`, `now_playing.song.*`, `live.is_live` |
| (tubafrenzy request) | `flowsheet_client.cpp` | `startShow()`, `addEntry()`, `endShow()` form body construction |
| `FlowsheetCreateSongFreeform` | `backend_service_client.cpp` | `addEntry()` JSON body construction |

### 5.5 Consumer Matrix

| Consumer | Language | Types Used |
|---|---|---|
| Orchestrator | TypeScript | All message types (`AutoDJWebSocketMessage` union), `AutoDJStatus`, `AutoDJDeactivateResponse`, `AutoDJActivationSource` |
| Management server | TypeScript | All message types (`AutoDJWebSocketMessage` union) |
| Backend-Service | TypeScript | `AutoDJDeviceStatus`, `AutoDJCommandAction` (if hosting management endpoints) |
| dj-site | TypeScript | `AutoDJStatus`, `AutoDJDeactivateResponse`, `AutoDJActivationSource`, `AutoDJCurrentTrack`, `AutoDJDeviceSummary` |
| Admin UI | TypeScript | `AutoDJDeviceStatus`, `AutoDJHeartbeat` |
| Arduino | C++ (ArduinoJson) | All message types (manual contract, not import) |
| tubafrenzy | Java | None (uses `X-Auto-DJ-Key` only; no management types) |

The `is_automation` field on `DJ`/`NewDJ` schemas will also propagate to:
- **Swift** (wxyc-ios-64) via existing code generation
- **Kotlin** (WXYC-Android) via existing code generation

A follow-up PR to each mobile app is needed to handle this field (e.g., filtering Auto DJ from DJ lists, displaying automated shows differently). See [Open Question 16](#8-open-questions).

### 5.6 AsyncAPI Consideration

OpenAPI 3.0 doesn't natively describe WebSocket protocols. The schemas are added to `api.yaml` as `components/schemas` only (no path definitions for WebSocket messages). The message direction and lifecycle are documented in prose with Mermaid sequence diagrams ([Section 3.6](#36-websocket-management-channel)).

If a formal WebSocket contract is needed later, [AsyncAPI](https://www.asyncapi.com/) 2.x can reference these same schemas. For now, the WebSocket has exactly one consumer (the Arduino), and the prose documentation is sufficient.

---

## 6. Flowsheet Client (historical)

> **This entire section is historical.** It documents the firmware's original on-device tubafrenzy flowsheet client (`flowsheet_client.cpp` / `TubafrenzyBackend`), which was **deleted** in the reporter re-architecture (§1). The current firmware writes no flowsheets; the orchestrator performs every flowsheet write against Backend-Service. The material below is retained as a record of the removed client and as reference for the orchestrator's equivalent operations.

### 6.1 Architecture (historical)

The pre-re-architecture firmware wrote to tubafrenzy only. There was no on-device dual-backend selector. Writing to Backend-Service is the responsibility of the [auto-dj-orchestrator](https://github.com/WXYC/auto-dj-orchestrator), which was built Backend-only — there is no `FLOWSHEET_BACKEND` flag (see [auto-dj-orchestrator#1](https://github.com/WXYC/auto-dj-orchestrator/issues/1)). See [Section 2.3](#23-flowsheet-write-architecture).

| Setting | Value |
|---|---|
| **Host** | `www.wxyc.info` |
| **Port** | `443` |
| **Auth header** | `X-Auto-DJ-Key: <key>` |
| **DJ ID** | `"0"` (string, no DJ table) |
| **Content type** | `application/x-www-form-urlencoded` |

### 6.2 tubafrenzy Client (removed)

Was implemented in `flowsheet_client.cpp` / `flowsheet_client.h`, both deleted in the reporter re-architecture. See [Section 3.3](#33-outbound-http-tubafrenzy-flowsheet-operations) for the historical protocol specification.

Three operations:

1. **`startShow(startingHourMs)`** → `int radioShowID`
   - POST form-encoded body to `/playlists/startRadioShow`
   - Parse `radioShowID` from 302 Location header
   - Return -1 on failure

2. **`addEntry(radioShowID, workingHourMs, artist, title, album)`** → `bool`
   - POST form-encoded body to `/playlists/flowsheetEntryAdd`
   - Includes `autoBreakpoint=true` (server handles hourly breakpoints)
   - Return true on 302

3. **`endShow(radioShowID)`** → `bool`
   - POST form-encoded body to `/playlists/finishRadioShow`
   - Includes `mode=signoffConfirm`
   - Return true on 302

### 6.3 Backend-Service Client (orchestrator)

The Backend-Service client is implemented in the [auto-dj-orchestrator](https://github.com/WXYC/auto-dj-orchestrator), not on the Arduino. See [Section 3.4](#34-backend-service-flowsheet-operations-via-orchestrator) for the full protocol specification.

The orchestrator implements the same four logical operations:

1. **`startShow(showName)`** → POST JSON to `/flowsheet/join` (Backend-Service resolves `dj_id` server-side)
2. **`addEntry(artist, title, album)`** → POST JSON to `/flowsheet`
3. **`endShow()`** → POST JSON to `/flowsheet/end`
4. **`addBreakpoint()`** → POST JSON to `/flowsheet` with `{ "message": "BREAKPOINT" }`

### 6.4 Request/Response Format Comparison

#### Start Show

| | tubafrenzy | Backend-Service |
|--|---|---|
| **URL** | `/playlists/startRadioShow` | `/flowsheet/join` |
| **Method** | POST | POST |
| **Content-Type** | `application/x-www-form-urlencoded` | `application/json` |
| **Auth** | `X-Auto-DJ-Key: <key>` | `Authorization: Bearer <JWT>` (orchestrator) |
| **Body** | `djID=0&djName=Auto+DJ&djHandle=AutoDJ&showName=Auto+DJ&startingHour=1708300800000` | `{"show_name": "Auto DJ"}` (orchestrator; `dj_id` resolved server-side) |
| **Success response** | 302 with Location header | 200 JSON: `{"id": 789, ...}` |
| **Show ID extraction** | Parse from Location header path | `response.id` |

#### Add Entry

| | tubafrenzy | Backend-Service |
|--|---|---|
| **URL** | `/playlists/flowsheetEntryAdd` | `/flowsheet` |
| **Method** | POST | POST |
| **Content-Type** | `application/x-www-form-urlencoded` | `application/json` |
| **Auth** | `X-Auto-DJ-Key: <key>` | `Authorization: Bearer <JWT>` (orchestrator) |
| **Body** | `radioShowID=123&workingHour=1708300800000&artistName=...&songTitle=...&releaseTitle=...&releaseType=otherRelease&autoBreakpoint=true` | `{"artist_name": "...", "album_title": "...", "track_title": "...", "request_flag": false}` |
| **Success response** | 302 | 200 JSON |

#### End Show

| | tubafrenzy | Backend-Service |
|--|---|---|
| **URL** | `/playlists/finishRadioShow` | `/flowsheet/end` |
| **Method** | POST | POST |
| **Content-Type** | `application/x-www-form-urlencoded` | `application/json` |
| **Auth** | `X-Auto-DJ-Key: <key>` | `Authorization: Bearer <JWT>` (orchestrator) |
| **Body** | `radioShowID=123&mode=signoffConfirm` | (empty; orchestrator identified by service JWT) |
| **Success response** | 302 | 200 JSON |

### 6.5 Client Architecture on Arduino

The pre-re-architecture firmware used a single `TubafrenzyBackend` implementation behind a `FlowsheetBackend` interface. Both were removed with the on-device flowsheet client; the current firmware has no flowsheet backend.

```mermaid
classDiagram
    class FlowsheetBackend {
        <<interface>>
        +startShow(showName: String) int
        +addEntry(artist: String, title: String, album: String) bool
        +endShow() bool
        +addBreakpoint() bool
    }

    class TubafrenzyBackend {
        -host: char*
        -port: int
        -apiKey: char*
        -radioShowID: int
        +startShow(showName: String) int
        +addEntry(artist: String, title: String, album: String) bool
        +endShow() bool
        +addBreakpoint() bool
    }

    class NetworkManager {
        +createClient() Client&
    }

    FlowsheetBackend <|.. TubafrenzyBackend
    TubafrenzyBackend --> NetworkManager : uses
```

The state machine code calls the `FlowsheetBackend` interface. `TubafrenzyBackend` accepts `NetworkManager&` for transport-agnostic HTTP. The `BackendServiceBackend` equivalent lives in the orchestrator (Node.js, not Arduino C++).
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

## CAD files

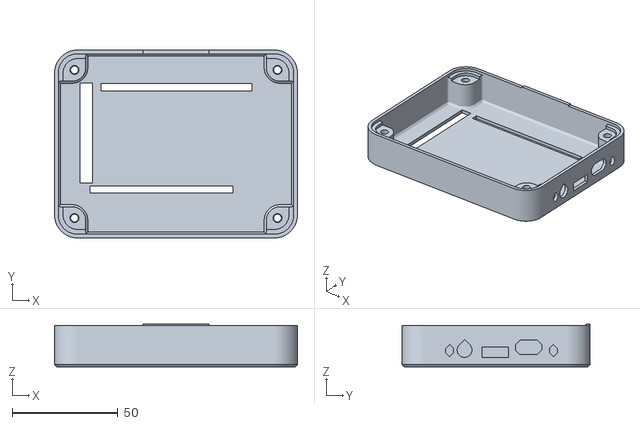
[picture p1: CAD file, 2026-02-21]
enclosure/original/shelf.stl
114.9 x 88.9 x 20.2

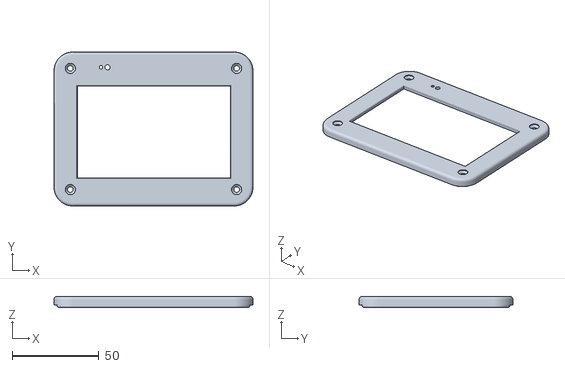
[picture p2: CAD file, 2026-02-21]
enclosure/original/lid.stl
114.9 x 88.9 x 6.45

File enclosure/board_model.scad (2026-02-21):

// board_model.scad — Simplified Ethernet Shield 3D model for verification
//
// A simplified 3D representation of the Arduino Ethernet Shield Rev2,
// built from EAGLE BRD data. Used for:
// - Visual cutout alignment verification (overlay inside case)
// - Interference detection (intersection with case walls)
// - Clearance gap visualization

include <config.scad>

module ethernet_shield_pcb() {
    // PCB outline (simplified rectangle — actual board has a notched corner)
    color(color_board)
        cube([eth_length, eth_width, eth_pcb_thickness]);
}

module rj45_housing() {
    // RJ45 jack housing (UC1)
    // Position: (-4.318, 38.354) in board coordinates
    // The housing overhangs the left board edge
    color(color_rj45)
        translate([
            rj45_board_x - rj45_housing_d + rj45_overhang,
            rj45_board_y - rj45_housing_w / 2,
            eth_pcb_thickness
        ])
            cube([rj45_housing_d, rj45_housing_w, rj45_housing_h]);
}

module sd_card_slot() {
    // Micro-SD card slot (X1) — rotated R270
    // Position: (63.5, 19.05) in board coordinates
    color(color_sd)
        translate([
            sd_board_x - sd_slot_d / 2,
            sd_board_y - sd_slot_w / 2,
            eth_pcb_thickness
        ])
            cube([sd_slot_d, sd_slot_w, sd_slot_h]);
}

module header_row(x, y, pins, pitch) {
    // Simplified header pin volume (rectangular block)
    header_length = pins * pitch;
    header_width = pitch;
    header_height_above = 8.5;  // stacking header total height above PCB
    header_height_below = 3.0;  // pin protrusion below PCB

    color([0.2, 0.2, 0.2, 0.6]) {
        // Above PCB (header housing + pins)
        translate([
            x - header_length / 2,
            y - header_width / 2,
            eth_pcb_thickness
        ])
            cube([header_length, header_width, header_height_above]);

        // Below PCB (pin protrusion through to GIGA R1)
        translate([
            x - header_length / 2,
            y - header_width / 2,
            -header_height_below
        ])
            cube([header_length, header_width, header_height_below]);
    }
}

module ethernet_shield() {
    // Complete Ethernet Shield model in board-local coordinates.
    // Origin at bottom-left mounting hole.
    ethernet_shield_pcb();
    rj45_housing();
    sd_card_slot();

    // Stacking headers
    header_row(power_header_x, power_header_y, power_header_pins, header_pitch);
    header_row(janalog_header_x, janalog_header_y, janalog_header_pins, header_pitch);
    header_row(jhigh_header_x, jhigh_header_y, jhigh_header_pins, header_pitch);
    header_row(jlow_header_x, jlow_header_y, jlow_header_pins, header_pitch);
}

module ethernet_shield_in_case() {
    // Ethernet Shield positioned in case coordinates at the correct
    // stacking height.
    translate([eth_board_origin_x, eth_board_origin_y, eth_pcb_bottom_z])
        ethernet_shield();
}

// When rendered directly, show the board in case position
ethernet_shield_in_case();

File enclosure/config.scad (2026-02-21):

// config.scad — Parameterized dimensions for GIGA R1 + Ethernet Shield enclosure
//
// All measurements in millimeters. Values derived from:
// - analyze_stl.py output (case geometry)
// - EAGLE BRD data (Ethernet Shield component positions)
// - Enclosure specification (docs/enclosure-specification.md)
//
// Adjust these parameters and re-render to tune fitment.


// ===================================================================
// STL file paths (relative to this file)
// ===================================================================

original_lid   = "original/lid.stl";
original_base  = "original/base.stl";
original_shelf = "original/shelf.stl";


// ===================================================================
// Case geometry (from analyze_stl.py)
// ===================================================================

// Lid bounding box: centered at origin
lid_x_min = -57.45;
lid_x_max =  57.45;
lid_y_min = -44.45;
lid_y_max =  44.45;
lid_z_min =   0.00;
lid_z_max =   6.45;

// Base bounding box: slightly asymmetric
base_x_min = -57.03;
base_x_max =  57.87;
base_y_min = -44.37;
base_y_max =  44.53;
base_z_min = -16.30;
base_z_max =   3.86;

// Case wall thickness (measured from lid analysis)
wall_thickness = 4.0;

// Display window opening in lid (from detailed lid analysis)
// The window is the uncovered region on the top face
window_x_min = -53.45;
window_x_max =  53.55;
window_y_min = -40.45;
window_y_max =  40.55;
window_z     =   6.45;  // top surface Z

// Window fill block — slightly oversized to ensure clean union
window_fill_margin = 0.5;  // mm extra on each side
window_fill_thickness = 3.5;  // mm thick (fills from inside surface to top)


// ===================================================================
// Board dimensions
// ===================================================================

// Arduino GIGA R1 WiFi
giga_length = 101.5;  // mm (X axis in board coords)
giga_width  =  76.2;  // mm (Y axis in board coords)
giga_pcb_thickness = 1.6;  // mm

// Arduino Ethernet Shield Rev2 (Uno form factor)
eth_length = 68.6;   // mm (X axis in board coords)
eth_width  = 53.3;   // mm (Y axis in board coords)
eth_pcb_thickness = 1.6;  // mm

// The Ethernet Shield is ~33 mm shorter than the GIGA R1
eth_giga_length_diff = giga_length - eth_length;  // ~32.9 mm


// ===================================================================
// Board-to-case coordinate transform
// ===================================================================

// The GIGA R1 board origin (bottom-left mounting hole) mapped to case
// coordinates. This positions the board inside the case.
//
// The GIGA R1 mounts on standoffs in the base. The Ethernet Shield
// plugs into the Uno-compatible headers on the GIGA R1.
//
// IMPORTANT: These offsets need verification against the actual STL
// mounting hole positions. Adjust after visual inspection in OpenSCAD.
//
// The GIGA R1's USB-C port faces the +X wall of the case.
// Board X=0 (mounting hole end) maps to the -X side of the case.

// Board origin in case coordinates
giga_board_origin_x = base_x_min + wall_thickness + 2.0;  // ~-51.03
giga_board_origin_y = (base_y_min + base_y_max) / 2 - giga_width / 2;  // centered in Y

// The Ethernet Shield sits at the same X origin as the GIGA R1's
// Uno-compatible headers. On the GIGA R1, these headers start at the
// board origin end (X=0). The Ethernet Shield's origin (mounting hole)
// aligns with the GIGA R1's Uno mounting hole.
eth_board_origin_x = giga_board_origin_x;
eth_board_origin_y = giga_board_origin_y;


// ===================================================================
// Stacking heights (Z coordinates in case space)
// ===================================================================

// Standoff height (GIGA R1 standoffs in base)
standoff_height = 5.0;  // mm above base floor

// Base floor Z
base_floor_z = base_z_min;

// GIGA R1 PCB bottom surface Z
giga_pcb_bottom_z = base_floor_z + standoff_height;

// GIGA R1 PCB top surface Z
giga_pcb_top_z = giga_pcb_bottom_z + giga_pcb_thickness;

// Stacking header height (between GIGA R1 top and Ethernet Shield bottom)
stacking_header_height = 8.5;  // mm (standard Arduino stacking headers)

// Ethernet Shield PCB bottom surface Z
eth_pcb_bottom_z = giga_pcb_top_z + stacking_header_height;

// Ethernet Shield PCB top surface Z
eth_pcb_top_z = eth_pcb_bottom_z + eth_pcb_thickness;


// ===================================================================
// Ethernet Shield component positions (from EAGLE BRD)
// All positions relative to board origin (bottom-left mounting hole)
// ===================================================================

// RJ45 jack (UC1)
rj45_board_x  = -4.318;   // mm — overhangs board edge by 4.3 mm
rj45_board_y  = 38.354;   // mm — center position along board edge
rj45_housing_w = 16.0;    // mm — housing width
rj45_housing_h = 13.5;    // mm — housing height
rj45_housing_d = 21.75;   // mm — housing depth (into board)
rj45_overhang  =  4.318;  // mm — overhang past board edge

// Micro-SD card slot (X1) — rotated 270 degrees
sd_board_x = 63.5;   // mm — at right edge of board
sd_board_y = 19.05;  // mm — center position
sd_slot_w  = 12.0;   // mm — slot width
sd_slot_h  =  2.5;   // mm — slot height
sd_slot_d  = 14.0;   // mm — slot depth

// Header positions (for board model)
// POWER header: (36.83, 2.54), 1x8, 2.54mm pitch
power_header_x = 36.83;
power_header_y = 2.54;
power_header_pins = 8;

// JANALOG header: (57.15, 2.54), 1x6, 2.54mm pitch
janalog_header_x = 57.15;
janalog_header_y = 2.54;
janalog_header_pins = 6;

// JHIGH header: (30.226, 50.8), 1x10, 2.54mm pitch, R180
jhigh_header_x = 30.226;
jhigh_header_y = 50.8;
jhigh_header_pins = 10;

// JLOW header: (54.61, 50.8), 1x8, 2.54mm pitch, R180
jlow_header_x = 54.61;
jlow_header_y = 50.8;
jlow_header_pins = 8;

header_pitch = 2.54;  // mm


// ===================================================================
// Port cutout dimensions (with clearances)
// ===================================================================

// RJ45 cutout: housing + 0.5mm clearance per side
rj45_cutout_w = 17.0;   // mm (16.0 + 0.5*2)
rj45_cutout_h = 14.5;   // mm (13.5 + 0.5*2)
rj45_cutout_depth = 10.0;  // mm — depth through wall (oversized)

// SD card cutout: slot + 0.5mm clearance per side
sd_cutout_w = 13.0;   // mm (12.0 + 0.5*2)
sd_cutout_h =  3.5;   // mm (2.5 + 0.5*2)
sd_cutout_depth = 10.0;  // mm

// SD card chamfer for fingernail access
sd_chamfer_depth = 1.5;  // mm
sd_chamfer_height = 2.0; // mm below the slot

// Terminal cutout: Euroblock envelope + 0.2mm printer tolerance per side
terminal_cutout_w = 18.4;  // mm (18.0 + 0.2*2)
terminal_cutout_h = 10.4;  // mm (10.0 + 0.2*2)
terminal_cutout_depth = 10.0;  // mm
terminal_corner_r = 1.0;  // mm (optional corner radius)

// Spacing between RJ45 and terminal cutouts
rj45_terminal_spacing = 6.0;  // mm edge-to-edge minimum


// ===================================================================
// Port cutout positions in case coordinates
// ===================================================================

// RJ45 is on the left wall (-X) of the case.
// The RJ45 jack overhangs the board edge, facing -X.
// Center Y: board_origin_y + rj45_board_y
// Center Z: eth_pcb_top_z + rj45_housing_h/2 (mounted on top of PCB)

rj45_case_y = eth_board_origin_y + rj45_board_y;
rj45_case_z = eth_pcb_top_z + rj45_housing_h / 2;

// Terminal cutout: same wall as RJ45, to the right (higher Y),
// vertically centered with RJ45
terminal_case_y = rj45_case_y + rj45_cutout_w / 2 + rj45_terminal_spacing + terminal_cutout_w / 2;
terminal_case_z = rj45_case_z;  // vertically centered with RJ45

// SD card is on the right wall (+X) of the case (or opposite short wall).
// The SD slot faces +X direction.
// Center Y: board_origin_y + sd_board_y
// Center Z: eth_pcb_top_z + sd_slot_h/2

sd_case_y = eth_board_origin_y + sd_board_y;
sd_case_z = eth_pcb_top_z + sd_slot_h / 2;

// Wall X positions for cutout placement
rj45_wall_x = base_x_min;      // left wall (RJ45 + terminal)
sd_wall_x   = base_x_max;      // right wall (SD card)


// ===================================================================
// Support post dimensions
// ===================================================================

// Contact point on Ethernet Shield underside (in board coordinates)
// Safe zone: x = 10-14 mm, y = 32-36 mm (from EAGLE BRD analysis)
support_post_board_x = 12.0;   // center of safe zone
support_post_board_y = 34.0;   // center of safe zone
support_post_diameter = 10.0;  // mm flat pad diameter

// Post position in case coordinates
support_post_case_x = eth_board_origin_x + support_post_board_x;
support_post_case_y = eth_board_origin_y + support_post_board_y;
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

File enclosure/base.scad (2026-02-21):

// base.scad — Modified base with port cutouts and support post
//
// Takes the original Display Shield base and adds:
// - RJ45 cutout on the left wall (-X)
// - Terminal cutout on the left wall (-X), right of RJ45
// - SD card cutout on the right wall (+X)
// - Support post rising from the base floor

include <config.scad>

module original_base() {
    import(original_base, convexity=10);
}

module rj45_cutout() {
    // RJ45 cutout through the left wall (-X).
    // Positioned using case coordinates derived from EAGLE BRD data.
    translate([
        rj45_wall_x - rj45_cutout_depth / 2,
        rj45_case_y,
        rj45_case_z
    ])
        cube([rj45_cutout_depth, rj45_cutout_w, rj45_cutout_h], center=true);
}

module sd_cutout() {
    // SD card cutout through the right wall (+X).
    translate([
        sd_wall_x + sd_cutout_depth / 2,
        sd_case_y,
        sd_case_z
    ])
        cube([sd_cutout_depth, sd_cutout_w, sd_cutout_h], center=true);
}

module sd_chamfer() {
    // Chamfer below the SD slot for fingernail access.
    translate([
        sd_wall_x + sd_chamfer_depth / 2,
        sd_case_y,
        sd_case_z - sd_cutout_h / 2 - sd_chamfer_height / 2
    ])
        // Angled cut: wider at the outside, narrower inside
        hull() {
            cube([sd_chamfer_depth, sd_cutout_w, 0.01], center=true);
            translate([0, 0, -sd_chamfer_height])
                cube([0.01, sd_cutout_w - 2, 0.01], center=true);
        }
}

module terminal_cutout() {
    // Terminal cutout through the left wall (-X), right of RJ45.
    // Vertically centered with RJ45 cutout.
    if (terminal_corner_r > 0) {
        translate([
            rj45_wall_x - terminal_cutout_depth / 2,
            terminal_case_y,
            terminal_case_z
        ])
            // Rounded rectangle cutout
            rotate([0, 90, 0])
                linear_extrude(terminal_cutout_depth, center=true)
                    offset(r=terminal_corner_r)
                        square([
                            terminal_cutout_h - 2 * terminal_corner_r,
                            terminal_cutout_w - 2 * terminal_corner_r
                        ], center=true);
    } else {
        translate([
            rj45_wall_x - terminal_cutout_depth / 2,
            terminal_case_y,
            terminal_case_z
        ])
            cube([terminal_cutout_depth, terminal_cutout_w, terminal_cutout_h], center=true);
    }
}

module support_post() {
    // Cylindrical support post from base floor to Ethernet Shield
    // underside. Flat pad on top for TPU/foam cushion.
    translate([support_post_case_x, support_post_case_y, base_floor_z])
        cylinder(
            h = support_post_height,
            d = support_post_diameter,
            $fn = $fn
        );
}

module modified_base() {
    union() {
        difference() {
            original_base();

            // Cut port openings
            rj45_cutout();
            sd_cutout();
            sd_chamfer();
            terminal_cutout();
        }

        // Add support post
        support_post();
    }
}

// Render the modified base
modified_base();

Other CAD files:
enclosure/original/base.stl
enclosure/lid.scad
enclosure/shelf.scad
enclosure/terminal_bracket.scad
enclosure/test_slices.scad

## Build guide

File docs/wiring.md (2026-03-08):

# Wiring Guide

## Hardware

- **Board:** Arduino Giga R1 WiFi
- **Relay:** Dry contact from mixing board AUX channel
- **Button:** Industrial 22mm mushroom head, momentary (spring return), 1NO+1NC, in control station enclosure
- **LED:** Standard LED + 220 ohm resistor (optional status indicator)

## Pin Assignments

| Pin | Function | Mode | Wiring |
|-----|---|---|---|
| D2 | Relay contact input | `INPUT_PULLUP` | Relay terminal -> D2, other terminal -> GND |
| D3 | Status LED | `OUTPUT` | D3 -> 220 ohm -> LED anode, cathode -> GND |
| D5 | Manual toggle button | `INPUT_PULLUP` | Button NO terminal -> D5, common terminal -> GND |
| GND | Common ground | -- | Shared with relay, button, and LED |
| LED_BUILTIN | Heartbeat | `OUTPUT` | Onboard LED (blinks every second) |

## Wiring Diagram

```
Mixing Board AUX Relay (dry contact)
    Terminal A ──────── D2 (INPUT_PULLUP)
    Terminal B ──────── GND

Manual Toggle Button (22mm mushroom head, momentary)
    NO terminal ──────── D5 (INPUT_PULLUP)
    Common terminal ──── GND

Status LED
    D3 ─── 220 ohm ─── LED (+) ─── LED (-) ─── GND
```

## How It Works

The mixing board has an AUX relay contact that reflects whether the AUX channel is enabled:

- **Relay open** (D2 reads HIGH via internal pullup): AUX is enabled, a live DJ is broadcasting.
- **Relay closed** (D2 reads LOW, pulled to GND): AUX is disabled, auto DJ is active.

The status LED mirrors this state:
- **LED on:** Auto DJ is active (relay closed).
- **LED off:** DJ is live (relay open).

The built-in LED blinks once per second as a heartbeat indicator.

## Manual Toggle Button

A 22mm industrial mushroom head button (momentary, spring return) in a control station enclosure box provides a physical toggle for the auto-DJ system. Pressing the button sends a toggle command to the orchestrator via the management channel. The orchestrator decides whether to activate or deactivate based on its current state.

The button uses the NO (normally open) contact. At rest, D5 reads HIGH (internal pullup). When pressed, the contact closes and D5 reads LOW (pulled to GND). The `ButtonMonitor` class detects this transition using the same 50ms debounce pattern as the relay.

The button does NOT directly control the Arduino's state machine. All activation logic lives in the orchestrator. Before the orchestrator is deployed, the button is wired and debounced but has no effect -- the Arduino continues to operate in relay-only mode.

**Pin choice:** D5 is used because D4 is the Ethernet Shield Rev2's SD card chip select (the shield's PCB connects D4 to the SD card slot even when unused). D10-D13 are reserved for the Ethernet Shield SPI bus.

## Debouncing

Both the relay and the button use 50ms software debounce. The pin state must remain stable for 50ms before a state change is registered. The relay debounce is in `relay_monitor.cpp`; the button debounce follows the same pattern in `button_monitor.cpp`.

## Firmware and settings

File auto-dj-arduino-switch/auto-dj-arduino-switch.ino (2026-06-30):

/**
 * Auto DJ Arduino Switch -- relay/button reporter
 *
 * Reports the mixing board's AUX relay state and a manual toggle button to the
 * auto-dj-orchestrator over a WebSocket management channel (HTTP fallback over
 * WiFi). The orchestrator owns all activation logic and flowsheet writes; this
 * board only reports inputs and drives the status LED.
 *
 * Hardware: Arduino Giga R1 WiFi (+ Ethernet Shield Rev2, Phase 2)
 * Wiring:   See docs/wiring.md
 *
 * Architecture: loop() is a thin I/O orchestrator that delegates all decision
 * logic to the pure tick() in state_machine.h and all JSON to mgmt_protocol.h.
 * See test/ for the desktop test suite.
 */

#include "config.h"
#include "secrets.h"
#include "relay_monitor.h"
#include "button_monitor.h"
#include "wifi_manager.h"
#include "state_machine.h"
#include "mgmt_protocol.h"
#include "mgmt_client.h"

// ========== Global state ==========

Context ctx = { BOOTING, false, false, TRANSPORT_NONE, false, 0, 0 };

// Telemetry
unsigned int reconnectCount = 0;
unsigned int buttonPressCount = 0;  // HTTP-fallback parity; reset after each heartbeat
unsigned long loopMaxMs = 0;        // max loop() duration since the last heartbeat
unsigned long lastReconnectAttemptMs = 0;

// ========== Modules ==========

// ledPin = -1: the state machine owns STATUS_LED_PIN (it factors in the
// orchestrator-reported active flag), so the relay monitor must not also drive it.
RelayMonitor relayMonitor(RELAY_PIN, -1, DEBOUNCE_MS);
ButtonMonitor buttonMonitor(BUTTON_PIN, DEBOUNCE_MS);
WifiManager wifiManager(WIFI_SSID, WIFI_PASS, WIFI_RETRY_INTERVAL_MS);
MgmtClient mgmt(ORCHESTRATOR_HOST, ORCHESTRATOR_PORT, ORCHESTRATOR_WS_PATH,
                ORCHESTRATOR_HB_PATH, ORCHESTRATOR_CMD_PATH, AUTO_DJ_KEY, ORCHESTRATOR_USE_TLS);

// ========== Helpers ==========

void logTransition(State prev, State next) {
    if (prev != next) {
        Serial.print("[State] ");
        Serial.print(stateName(prev));
        Serial.print(" -> ");
        Serial.println(stateName(next));
    }
}

HeartbeatFields makeHeartbeat(const Context& c, const Inputs& in) {
    HeartbeatFields f;
    f.state = stateName(c.state);
    f.transport = c.transport == TRANSPORT_ETHERNET ? "ethernet" : "wifi";
    f.uptime_s = in.currentMillis / 1000;
    f.wifi_rssi_null = c.transport == TRANSPORT_ETHERNET;
    f.wifi_rssi = (long)WiFi.RSSI();
    f.free_ram = 0;  // Giga/Mbed: heap stats not reported here (telemetry only)
    f.firmware_version = FIRMWARE_VERSION;
    f.config_hash = "";
    f.loop_max_ms = loopMaxMs;
    f.reconnect_count = reconnectCount;
    f.tracks_detected = 0;  // reporter model: orchestrator owns track detection
    f.tracks_posted = 0;
    f.errors_since_boot = 0;
    f.button_press_count = buttonPressCount;
    f.relay_auto_dj_active = c.relayAutoDJActive;
    return f;
}

// ========== Setup ==========

void setup() {
    Serial.begin(115200);
    while (!Serial && millis() < 3000);
    Serial.println();
    Serial.println("=== WXYC Auto DJ Reporter ===");

    pinMode(STATUS_LED_PIN, OUTPUT);
    relayMonitor.setUp();
    buttonMonitor.setUp();
    wifiManager.setUp();
    mgmt.setUp();  // register auth header + callbacks once

    if (wifiManager.isConnected() && mgmt.connectWs()) {
        reconnectCount++;
        lastReconnectAttemptMs = millis();
    }
}

// ========== Main loop ==========

void loop() {
    unsigned long loopStart = millis();

    relayMonitor.update();
    buttonMonitor.update();
    wifiManager.update();
    mgmt.poll();

    bool wifiUp = wifiManager.isConnected();
    bool channelUp = mgmt.channelUp();

    // Reconnect the management channel if the network is up but the channel
    // dropped — rate-limited so a refusing/down orchestrator can't be hammered
    // every loop iteration (connect() returns immediately when refused).
    if (wifiUp && !channelUp &&
        (millis() - lastReconnectAttemptMs >= WIFI_RETRY_INTERVAL_MS)) {
        lastReconnectAttemptMs = millis();
        if (mgmt.connectWs()) {
            reconnectCount++;
            channelUp = mgmt.channelUp();
        }
    }

    // ---- Gather inputs ----
    Inputs in;
    in.relayChanged = relayMonitor.stateChanged();
    in.relayAutoDJActive = relayMonitor.isAutoDJActive();
    in.buttonPressed = buttonMonitor.pressed();
    in.ethernetLinkUp = false;  // Ethernet shield: Phase 2
    in.wifiConnected = wifiUp;
    in.channelUp = channelUp;

    String cmdId;
    in.gotCommand = mgmt.takeCommand(&in.commandAction, &cmdId);
    if (!in.gotCommand) in.commandAction = CMD_NONE;
    in.gotActiveResult = mgmt.takeActiveResult(&in.activeResult);

    in.currentMillis = millis();
    in.heartbeatIntervalMs = WS_HEARTBEAT_MS;
    in.retryBackoffMs = RETRY_BACKOFF_MS;
    in.maxRetries = MAX_RETRIES;

    if (in.buttonPressed) buttonPressCount++;

    // ---- Tick (pure) ----
    State prev = ctx.state;
    TickResult r = tick(ctx, in);
    ctx = r.context;
    logTransition(prev, ctx.state);

    // ---- Post-tick I/O (ordered) ----
    if (r.sendAck) {
        mgmt.send(buildAck(cmdId, r.ackStatus));
    }
    if (r.sendButtonToggle) {
        mgmt.send(buildButtonToggle(wifiManager.getEpochTime()));
    }
    if (r.sendHeartbeat) {
        mgmt.send(buildHeartbeat(makeHeartbeat(ctx, in)));
        buttonPressCount = 0;  // reset the parity counter after reporting
        loopMaxMs = 0;         // reset the loop-latency max so it tracks per-interval
    }
    if (r.doRestart) {
        NVIC_SystemReset();
    }
    // tick() always sets setLed to 0/1 (the state machine owns STATUS_LED_PIN).
    digitalWrite(STATUS_LED_PIN, r.setLed ? HIGH : LOW);
    if (r.delayMs > 0) {
        delay(r.delayMs);
    }

    unsigned long elapsed = millis() - loopStart;
    if (elapsed > loopMaxMs) loopMaxMs = elapsed;
}

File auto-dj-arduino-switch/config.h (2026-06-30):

#ifndef CONFIG_H
#define CONFIG_H

// ========== Pin Assignments ==========
#define RELAY_PIN 2        // Mixing board AUX relay contact (INPUT_PULLUP)
#define STATUS_LED_PIN 3   // External status LED (on = auto-DJ active)
#define BUTTON_PIN 5       // Manual toggle button, INPUT_PULLUP, NO contact

// ========== Timing (milliseconds) ==========
#define DEBOUNCE_MS 50
#define WS_HEARTBEAT_MS 30000          // Management-channel heartbeat (Ethernet/WS)
#define HTTP_POLL_INTERVAL_MS 60000    // Management-channel poll (WiFi fallback)
#define WIFI_RETRY_INTERVAL_MS 5000    // 5s WiFi reconnect delay
#define MAX_RETRIES 3
#define RETRY_BACKOFF_MS 2000          // Base backoff between transport retries

// ========== Orchestrator management channel ==========
// In local/staging the orchestrator is plain ws:// on the host's LAN IP; in
// production it is wss:// behind a hostname. Set ORCHESTRATOR_USE_TLS to 1 for
// production.
#define ORCHESTRATOR_HOST "192.168.1.50"   // host LAN IP (local/staging) or hostname (prod)
#define ORCHESTRATOR_PORT 8090
#define ORCHESTRATOR_WS_PATH "/api/auto-dj/ws"
#define ORCHESTRATOR_HB_PATH "/api/auto-dj/heartbeat"
#define ORCHESTRATOR_CMD_PATH "/api/auto-dj/commands"
#define ORCHESTRATOR_USE_TLS 0             // 0 = ws:// (local/staging), 1 = wss:// (prod)

// ========== Firmware ==========
#define FIRMWARE_VERSION "2.0.0"

// ========== NTP ==========
// Still needed for the button_toggle timestamp and heartbeat uptime telemetry.
#define NTP_SERVER "pool.ntp.org"
#define UTC_OFFSET_SECONDS -18000 // Eastern Time (UTC-5)

#endif

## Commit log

2026-02-18 Initial Arduino sketch for auto DJ flowsheet bridge
    Arduino Giga R1 WiFi monitors the mixing board AUX relay contact
    to detect when auto DJ is active. Polls AzuraCast for track data
    and writes entries to the tubafrenzy flowsheet via HTTP POST.
    Modules:
    - relay_monitor: debounced relay input with LED indicator
    - wifi_manager: WiFi connection with auto-reconnect
    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
2026-02-18 Add desktop tests for pure functions
    Extract urlEncode, parseRadioShowID, and currentHourMs into utils.h/utils.cpp
    as free functions, testable on desktop without Arduino SDK. Refactor
    flowsheet_client.cpp and .ino to use the extracted functions.
    Desktop test suite uses GoogleTest with a minimal Arduino String shim.
    19 tests covering URL encoding edge cases, Location header parsing,
    and hour truncation logic. CI workflow runs tests on push and PR.
2026-02-21 Convert ASCII diagrams to Mermaid in README
    Replace the architecture and state machine ASCII art with Mermaid
    flowchart and stateDiagram-v2 blocks for rendered diagrams on GitHub.
2026-02-21 Extract state machine into testable pure tick() function
    The 7-state state machine logic (transitions, retry/backoff, WiFi recovery,
    polling decisions) was inlined in loop() and coupled to hardware I/O. Extract
    it into a pure tick() function that takes a Context + Inputs snapshot and
    returns a TickResult with the updated state plus post-transition actions.
    32 new GoogleTest cases cover all states, transitions, retry behavior,
    WiFi loss recovery, and edge cases. Rename the CMake test library from
    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
2026-02-21 Refactor .ino loop() into thin orchestrator calling tick()
    Replace the inline state machine switch with a three-phase pattern:
    gather inputs -> pre-tick I/O -> tick() -> post-tick actions. The
    orchestrator's I/O dispatch is a mechanical switch with no decision
    logic; all transition/retry/edge-detection logic lives in tick().
    [auto-dj-arduino-switch.ino]
2026-02-21 Add comprehensive networking specification
    Create docs/networking-spec.md covering all network traffic for the Auto DJ
    Arduino Switch: both flowsheet backends (tubafrenzy and Backend-Service),
    WebSocket management protocol, AzuraCast Centrifugo relay, authentication
    and credentials, wxyc-shared type contracts, and dual-backend client
    abstraction.
    Add deprecation note to remote-access-roadmap.md pointing to the new spec.
    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
2026-02-21 Add enclosure design for GIGA R1 + Ethernet Shield Rev2
    Parameterized OpenSCAD enclosure based on Printables model 605051
    (GIGA Display Shield case), modified for the Ethernet Shield Rev2:
    - Lid: display window filled solid for dust resistance
    - Base: RJ45, SD card, and Euroblock terminal cutouts + support post
    - Shelf: matching aligned port cutouts
    - Terminal bracket: new part with M3 mounts, dust lip, strain relief
    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
    [base.scad, base.stl, board_model.scad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]
2026-02-21 Add testing strategy section to networking spec
    Add Section 6.7 documenting the FakeClient pattern for Arduino-side tests,
    server-side request/response testing approach, and the wxyc-shared api.yaml
    contract that ties both sides together. Maps each protocol from Section 3
    to specific test fixtures and assertions.
2026-02-21 Expand testing strategy with WebSocket and server-side coverage
    Section 6.7 now covers:
    - Arduino-side FakeWebSocket tests for all five management message types
    - Backend-Service endpoint tests (flowsheet join/add/end, is_automation filter)
    - Management server WebSocket tests (heartbeat ingestion, command delivery,
    ack processing, connection lifecycle, stale heartbeat detection)
    - Centrifugo relay transform tests (AzuraCast JSON -> flat AutoDJNowPlaying)
    - Shared test fixture strategy with canonical JSON per message type
2026-02-21 Document direct AzuraCast Centrifugo WebSocket subscription
    AzuraCast exposes a public WebSocket endpoint for now-playing data at
    /api/live/nowplaying/websocket -- no authentication required. The Arduino
    can subscribe directly over Ethernet without relaying through the
    management server, reducing latency and failure modes.
    Section 3.9: Rewritten from relay-based to direct WebSocket architecture
    with dual-mode state machine (push over Ethernet, poll over WiFi).
    Section 2.1: Updated topology diagram (direct WSS line to AzuraCast).
    Section 2.4: Management server no longer responsible for now-playing relay.
    Section 3.1: Added row for direct AzuraCast WebSocket in traffic table.
    Section 3.6.1: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
2026-02-21 Make networking spec self-contained; remove roadmap references
    Copy all content from remote-access-roadmap.md that was previously only
    referenced by link: KVStore boot sequence diagram, Ethernet Shield pin
    table, SSLClient vs Mbed TLS comparison, HTTP client migration code
    example, studio prerequisites checklist, OTA sequence diagram and
    safeguards table.
    Remove all cross-references to remote-access-roadmap.md. The networking
    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
2026-02-22 Fix networking spec inconsistencies from merge conflict resolution
    Resolve merge conflicts and fix resulting inconsistencies:
    - Restore direct Arduino ↔ AzuraCast WebSocket row (#8) in the traffic
    summary table, replacing the Mgmt Server ↔ Centrifugo relay row that
    contradicted the document's recommendation for direct subscription
    - Rename Phase 3 title from "AzuraCast Relay" to "AzuraCast Direct
    WebSocket" to match the body text
    - Move AzuraCast direct WebSocket task (p2f) from Phase 3 to Phase 2
    section in the Gantt chart, matching its dependency and ID prefix
    - Convert all remaining ASCII arrows (->) to Unicode (→) for
    consistency across testing tables, comparison tables,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
2026-02-22 Add sequence diagrams for flowsheet lifecycle, Centrifugo, and credential rotation
    Add three Mermaid sequence diagrams to visualize protocol flows that
    were previously described only in prose and tables:
    - Section 3.4.5: Show lifecycle comparison diagram showing tubafrenzy
    (302 redirects, auto-breakpoints) vs Backend-Service (200 JSON,
    explicit breakpoints) side by side
    - Section 3.9.1: Replace the Centrifugo connection sequence numbered
    list with a diagram showing WebSocket upgrade, subscription, track
    updates, and reconnection with exponential backoff and recovery
    - Section 4.6: Two credential rotation diagrams -- API key rotation
    (dual-key window handshake) and Backend-Service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
2026-02-22 Expand architecture section with consolidated role definitions
    Section 2.4 (Management Server) was a thin bullet list that deferred
    everything to protocol sections scattered across the doc. Expanded it
    into a full responsibilities table with cross-references, dual-transport
    interface summary, and auth model overview.
    Added Section 2.5 (AzuraCast) to frame its dual-mode now-playing role
    (HTTP poll vs. Centrifugo WebSocket) and clarify its boundary as a
    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
2026-02-22 Reframe Phase 0 DST as display convenience, not flowsheet correctness
    Flowsheet timestamps (startingHour, workingHour) are UTC epoch
    milliseconds from NTP and are correct year-round without timezone
    logic. Breakpoint insertion also works correctly because UTC hour
    boundaries align with Eastern hour boundaries (whole-hour offset).
    UTC_OFFSET_SECONDS is defined in config.h but never referenced.
    DST awareness is only needed for human-readable output: serial debug
    logs, heartbeat telemetry, and admin UI display. Introduce
    localEpoch() for formatting local times; currentHourMs() stays on
    raw UTC.
2026-02-22 Document Backend-Service mirror and backend rollback rationale
    Section 2.3: Add data flow and mirroring context -- Backend-Service mirrors
    to tubafrenzy, so dual-backend support serves both migration (switch to
    Backend-Service, tubafrenzy stays populated via mirror) and rollback (switch
    back to tubafrenzy if Backend-Service has bugs).
    Section 3.6.4: Explain why wifi_ssid/wifi_pass and flowsheet_backend are
    not hot-reloadable (WiFi.begin() blocks 36s; backend switch mid-show leaves
    new client without show context).
2026-02-23 Fix remaining deployment-assuming language in networking-spec.md
    Replace present-tense language that assumes the device is already
    assembled and installed: "sits" → "will sit", "Today, every" →
    "Once deployed, every", "requires" → "would require", "There is no
    way" → "There would be no way". Change "in production today" →
    "implemented functionality", "the device already makes" → "the
    firmware already implements", "current production behavior" →
    "current implemented behavior". Replace all "Live" status labels
    with "Implemented" since the unit has not yet been assembled or
    deployed.
2026-02-23 Remove hedging language from purpose statement
    The spec defines the WebSocket management channel in detail (Section
    3.6), so describing it as something the device "will eventually"
    do undercuts the document. State it as fact.
2026-02-23 Remove hedging from SD card slot note
    "in the future" adds nothing -- the option is stated either way.
2026-02-23 Replace OpenSCAD cross-section pipeline with Python STL slicer
    OpenSCAD 2021.01's projection(cut=true) fails on the ~83K-triangle
    output meshes due to a CGAL Nef polyhedron assertion. Replace the
    OpenSCAD-based cross_sections.scad with cross_section.py, which
    slices the already-rendered output STLs directly using triangle-plane
    intersection (no external dependencies).
    The script also computes effective slice heights by intersecting each
    cutout's Z range with the case wall bounds, since the cutout center Z
    (e.g. RJ45 at 7.15 mm) can exceed the wall top (3.86 mm).
    [cross_sections.scad]
2026-02-23 Add CLAUDE.md and update enclosure README build instructions
    Add project-level CLAUDE.md with repo layout, firmware architecture,
    testing, and enclosure build conventions.
    Update enclosure README: fix OpenSCAD install command (--cask), reorder
    build targets by typical workflow, add make clean.
2026-02-23 Add dependency injection and mock-based desktop tests for I/O modules
    Refactor RelayMonitor, AzuraCastClient, and FlowsheetClient to support
    desktop testing via dependency injection:
    - RelayMonitor: parameterized update(millis, reading) bypasses GPIO
    - AzuraCastClient: poll(Client&) replaces hardcoded WiFiSSLClient
    - FlowsheetClient: Client& parameter on all public/private methods
    - .ino: creates WiFiSSLClient at each call site and passes it in
    Expand the Arduino shim with Print/Stream/Client hierarchy, Printable,
    GPIO stubs, and controllable millis(). Compile real ArduinoHttpClient
    and ArduinoJson libraries on desktop via CMake FetchContent. FakeClient
    test helper pre-loads HTTP responses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
    [auto-dj-arduino-switch.ino, relay_monitor.cpp]
2026-03-08 Add virtual switch API spec, button wiring, and dj-site UI design
    Spec the three new capabilities needed for the auto-DJ toggle feature:
    1. Virtual switch API (orchestrator): activate, deactivate, and status
    endpoints for dj-site, with conflict resolution rules for three
    activation sources (virtual switch, physical button, relay)
    2. Physical button: 22mm mushroom head on D5, debounced, sends
    button_toggle messages to orchestrator via management channel
    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
2026-03-08 Fix five inconsistencies in plan document
    - "toggle" -> "button_toggle" in activation sources table
    - AutoDJActivateResponse -> AutoDJStatus (activate returns the same shape as the status endpoint, not a separate type)
    - "config.h docs" -> "remote-administration.md" in scope list
    - Remove unspecced unauthenticated minimal response from status endpoint
    - "flows back as a command" -> "flows back as an ack" for button toggle
2026-03-28 Delegate all Backend-Service communication to orchestrator
    The Arduino no longer communicates with Backend-Service directly. All flowsheet writes to Backend-Service are delegated to the auto-dj-orchestrator, which authenticates as a service identity using standard JWT refresh. This eliminates the PAT vs JWT conflict — the Arduino's constrained environment cannot perform JWT refresh, but the orchestrator (server-side Node.js) handles it naturally.
    Sections updated: 1.2 (problem statement), 1.3 (scope), 2.1 (network topology — remove Arduino → Backend-Service arrow), 2.3 (reframe as orchestrator-mediated flowsheet writes), 2.4 (remove PAT rotation responsibility), 3.1 (traffic summary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
2026-06-30 feat: re-architect firmware into a relay/button reporter
    Pivot the Arduino from a flowsheet writer into a "dumb" reporter. The orchestrator now owns AzuraCast subscription, activation logic, and all flowsheet writes; this board reports the relay state and 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
    Removed: azuracast_client, flowsheet_client, utils (url-encode / radioShowID / hour math were flowsheet-only) and their tests.
    Added:
    - button_monitor (D5, INPUT_PULLUP, NO contact, 50ms debounce, press-edge) — clones the relay_monitor pattern, fully desktop-tested.
    - mgmt_protocol (pure ArduinoJson): heartbeat / button_toggle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
2026-06-30 fix(review): transport/channel correctness, command queue, reconnect backoff, doc sync
    Addresses /code-review max findings on the firmware re-architecture.
    State machine (testable):
    - CONNECTED now requires BOTH a live link AND the management channel; a WS drop returns to CONNECTING so the reconnect/backoff path engages instead of silently dropping sends.
    - CONNECTING requires channelUp to reach CONNECTED, and can fall back to WiFi even when the Ethernet link is up but its channel never came up (no CONNECTING<->ERROR ping-pong). Added tests.
    mgmt_client (device I/O, not CI-compiled):
    - Replaced the single-slot command inbox with an 8-deep FIFO; ws.poll() can dispatch several frames at once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
    [auto-dj-arduino-switch.ino, relay_monitor.cpp]
2026-07-28 docs(networking-spec): mark the removed tubafrenzy write path as historical
    The reporter re-architecture (9facefc) deleted the firmware's on-device flowsheet_client.cpp and azuracast_client.cpp: the Arduino no longer writes to tubafrenzy or polls AzuraCast, it reports studio state to the orchestrator over the management channel. The networking spec still presented those paths as "Status: Implemented" and asserted in the present tense that the Arduino writes to tubafrenzy, contradicting the re-architecture note at the top of the same file.
    Reconcile the spec so nothing presents a tubafrenzy write path as current firmware behavior: mark the AzuraCast-poll and tubafrenzy-POST rows Removed in t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
